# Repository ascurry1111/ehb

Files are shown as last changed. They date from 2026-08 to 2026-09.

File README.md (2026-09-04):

# EHB — Electric Handbells

Umbrella repo for a family of electric/electronic handbell products. Each
product's source is self-contained under `products/<name>/` — its own
README, 3D-print files, firmware, app code, and changelog live there and
don't mix with any other product's.

## Products

| Folder | Product | Status |
|---|---|---|
| [`products/electric-handbell`](products/electric-handbell/) | Solid-state electronic handbell: 3D-printed bell body with no moving parts, accelerometer-triggered wireless sound (BLE) | Active — v0.2 released |
| [`products/song-bell`](products/song-bell/) | Simpler 3D-printed bell that plays a song on its own | Planned |
| [`products/bell-pickup`](products/bell-pickup/) | Electronic adapter/pickup that retrofits onto a real (physical-clapper) handbell to trigger sound electronically | Planned |

See each product's own README for hardware, firmware, and build details.

## Repo conventions

- One folder per product under `products/`, each independently buildable —
  no product's firmware/app/model files reference another's.
- A shared root [`.gitignore`](.gitignore) covers common build/editor
  junk (Gradle, Arduino/PlatformIO, Python, OpenSCAD backups) across all
  products, since those patterns aren't product-specific.
- Per-product changelogs (e.g.
  [`products/electric-handbell/CHANGELOG.md`](products/electric-handbell/CHANGELOG.md))
  rather than one repo-wide log, since products version independently.

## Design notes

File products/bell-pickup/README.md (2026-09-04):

# Bell Pickup

An electronic adapter/pickup that retrofits onto a **real** handbell (one
with an actual clapper) to sense rings and trigger sound electronically —
unlike [`../electric-handbell`](../electric-handbell/), which is a
fully 3D-printed bell body with no moving parts, this attaches to an
existing physical bell.

**Status: planned.** Nothing has been designed yet; this folder is
scaffolding, kept separate from
[`../electric-handbell`](../electric-handbell/) so this product's files
never mix with that one's.

## Anticipated layout

```
3dprint/    Mounting/adapter hardware for attaching the pickup to a real bell
firmware/   Sensor + wireless firmware for the pickup
```

Likely shares a fair amount of firmware DNA with
[`../electric-handbell/firmware`](../electric-handbell/firmware/)
(accelerometer-based ring detection) — worth starting from a copy of that
rather than from scratch, though the mounting/sensing details will differ
since this senses a real clapper strike rather than being cast into a
purpose-built body.

Add a `CHANGELOG.md` here once there's a first release to log. Adjust the
layout above as the actual design takes shape — it's a starting point, not
a commitment.

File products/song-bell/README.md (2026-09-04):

# Song Bell

A simpler 3D-printed bell that plays a song on its own — no companion
receiver, no phone, no transmitter/receiver pair. Print the body, add the
electronics, and it plays a tune by itself.

**Status: planned.** Nothing has been designed yet; this folder is
scaffolding, kept separate from
[`../electric-handbell`](../electric-handbell/) so this product's files
never mix with that one's.

## Anticipated layout

Following the convention used by
[`../electric-handbell`](../electric-handbell/):

```
3dprint/    OpenSCAD model for the bell body
firmware/   Microcontroller firmware for on-board song playback
```

Add a `CHANGELOG.md` here once there's a first release to log. Adjust the
layout above as the actual design takes shape — it's a starting point, not
a commitment.

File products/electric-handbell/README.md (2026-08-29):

# Electric Handbell

A solid-state electronic handbell: a 3D-printed bell body with no moving
parts, instrumented with an accelerometer to detect ring gestures and
trigger sound electronically/wirelessly instead of with a physical clapper.

## Repo layout

```
3dprint/    OpenSCAD model for the bell body and printed test pieces
firmware/   ESP32 firmware (transmitter + receiver) and PC test tooling
android/    Android app for the v0.2 live-demo receiver (BLE-only)
```

## Hardware

- [Adafruit LIS3DH](https://www.adafruit.com/product/2809) accelerometer — senses the swing/ring motion
- [Adafruit ESP32 Feather V2](https://www.adafruit.com/product/5400) — reads the LIS3DH over I2C, transmits ring events wirelessly via ESP-NOW or BLE

See [firmware/README.md](firmware/README.md) for wiring, bring-up steps, and details on the wireless protocol.

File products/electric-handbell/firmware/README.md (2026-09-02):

# Wireless Handbell Prototype

## What's in here

```
feather_transmitter/feather_transmitter.ino   Feather ESP32 V2 — ring detection, BLE tx (v0.2: BLE-only)
devkit_receiver/devkit_receiver.ino           ESP32-DEVKITC-V4 — ESP-NOW rx, forwards to USB serial (v0.1 path)
receiver_tests/pc_serial_listener.py          PC — plays a tone from the ESP-NOW/serial path (v0.1 path)
receiver_tests/pc_ble_listener.py             PC — plays a tone from the BLE path directly
```

**v0.2 note:** `feather_transmitter.ino` was changed to BLE-only for the
Android demo (Android has no ESP-NOW support), which also removes the
WiFi/BLE radio-coexistence jitter noted below. The ESP-NOW + BLE dual-transport
version, and `devkit_receiver.ino`/`pc_serial_listener.py`'s upstream
counterpart, are preserved at the `v0.1` git tag if you need that path again.
For the live demo, see [`../android/HandbellReceiver`](../android/HandbellReceiver)
instead of the PC listeners.

## Wiring

LIS3DH → Feather ESP32 V2 (I2C):
- VIN → 3V
- GND → GND
- SDA → SDA
- SCL → SCL

If you have the STEMMA QT versions of both boards, just use the STEMMA QT cable and skip the wiring above entirely.

## Bring-up order (v0.2, BLE-only demo path)

0. **Set the mounting orientation first** — see [Ring detection](#ring-detection) below. Nothing will trigger correctly until `FORWARD_AXIS`/`FORWARD_SIGN` match your physical mounting.
1. **Flash `feather_transmitter.ino`** to the Feather. Open its Serial Monitor at 115200 baud — you should see its BLE address printed, then `RING #n peak=...g swing=...m/s` lines whenever you swing the bell forward and stop it.
2. **Test the BLE → PC path** (quick sanity check without the phone app): run `pc_ble_listener.py`. Swing the bell — you should hear a tone on the PC.
3. **Test the BLE → phone path**: build and run the Android app in
   [`../android/HandbellReceiver`](../android/HandbellReceiver) on the demo
   phone. Swing the bell — you should see the ring counter increment and hear
   a tone from the phone.

## Bring-up order (v0.1, ESP-NOW + BLE dual-transport — see the `v0.1` git tag)

1. **Flash `devkit_receiver.ino`** to the ESP32-DEVKITC-V4 first and open its Serial Monitor at 115200 baud. It prints its own MAC address on boot — copy it.
2. **Paste that MAC** into `RECEIVER_MAC` near the top of `feather_transmitter.ino`.
3. **Flash `feather_transmitter.ino`** to the Feather. Open its Serial Monitor too — you should see `My MAC: ...` and then `RING #n peak=...g` lines whenever you swing/tap the accelerometer.
4. Watch the DEVKITC-V4's Serial Monitor — you should see matching `RING,...` lines arrive there over ESP-NOW.
5. **Test the ESP-NOW → PC path**: run `pc_serial_listener.py --list` to find the DEVKITC-V4's port, then `pc_serial_listener.py --port <that port>`. Swing the bell — you should hear a tone.
6. **Test the BLE → PC path**: run `pc_ble_listener.py` (the DEVKITC-V4 isn't involved in this path at all — the Feather talks straight to the PC's Bluetooth radio). Swing the bell — you should hear a tone.

## Ring detection and damp

Detection models how a real handbell actually rings — a forward swing followed
by a **sudden stop** (which is when the clapper catches up and strikes) — rather
than "acceleration crossed a threshold," which is why earlier versions rang when
you merely picked the bell up or tapped the handle. See the `RING DETECTION`
comment at the top of `feather_transmitter.ino` for the full rationale.

A real handbell keeps ringing after the strike until it naturally damps out, or
until the ringer presses it to their body to stop it. The Android app plays a
multi-second decaying tone per ring rather than a short blip, and **damp** is
the gesture that cuts it short.

**Ring and damp are deliberately not symmetric.** A ring is directional — the
clapper only travels fore/aft and is sprung against striking backward. A damp
is *omnidirectional*: physically it's just "the casting contacted something,"
and in practice arm geometry means the bell usually comes back to the body
around 45° off the ring plane, laterally. So the stop is detected on the
**full 3D velocity vector**, as a deceleration measured *along the direction
of travel* rather than along any fixed axis.

**Both gestures share one armed state, and which one a motion was is decided
at the stop** — from the peak forward velocity accumulated over the whole
gesture — not when it arms. An earlier version armed each gesture separately
and that could not work: `speed >= |forwardVelocity|` by definition, so on a
forward swing the damp arm always tripped first and stole a large share of
rings, which then landed as silent damps. See `DECIDE AT THE STOP` in the
sketch's header comment for the full write-up; it's the kind of mistake worth
not repeating.

### Mounting orientation

`FORWARD_AXIS` / `FORWARD_SIGN` must match the physical mounting or nothing
works. They're preset to `AXIS_Z` / `-1.0` for the current build: the LIS3DH is
mounted flat on the rod's wide face with the component side outward, so the PCB
normal (Z) points at the ringer and forward — away from the ringer — is `-Z`.

**Verify the sign before tuning anything else.** The axis is confidently Z, but
the sign depends on which way the board faces and is easy to get backwards; a
flipped sign arms the detector on the backswing. Set `CALIBRATION_MODE 1`,
reflash, open Serial Monitor at 115200:

1. Hold the bell still in the ready position. The **dominant** `g=[]` value
   should be the in-plane axis running along the rod, with Z a minority
   component. If Z dominates, the board isn't mounted the way this config
   assumes and both settings need re-deriving.
2. Swing forward and confirm `vFwd` goes strongly **positive**. If it goes
   negative, flip `FORWARD_SIGN`.
3. Return `CALIBRATION_MODE` to `0`, reflash.

### Then: tune the thresholds

Every ring and damp prints `peakFwd=` and `peakSpd=`. Ring and damp several
times each and compare those numbers — that's the fastest way to see whether
the thresholds sit in the right place.

- **`RING_FORWARD_VELOCITY`** (m/s) — the ring/damp discriminator. At the
  stop, a gesture whose peak forward velocity reached this is a ring;
  anything less is a damp. **Lower it** if gestures you meant as rings are
  landing silently (check whether their `DAMP peakFwd=` sits just under this
  value — that's the tell). **Raise it** if damps are ringing the bell.
- **`RING_STOP_DECEL_THRESHOLD`** / **`DAMP_STOP_DECEL_THRESHOLD`** (m/s²) —
  how abruptly the bell must stop for each gesture to fire, measured along the
  direction of travel. Separate values because they're physically different
  events: arresting a committed swing versus resting the casting against your
  shoulder, so the damp threshold is set much lower. **Lower** whichever
  gesture is being missed entirely (nothing prints at all); **raise** it if
  incidental handling triggers that gesture.
- **`DAMP_CONTACT_JERK`** (m/s³) — how *suddenly* the deceleration must arrive
  for a damp to count as a contact. This exists because the damp threshold
  alone can't do the job: as you slow your arm approaching your shoulder, that
  voluntary slowdown produces a deceleration of similar *magnitude* to a gentle
  contact, so lowering the threshold enough to catch soft damps also makes it
  fire mid-approach, before the casting touches anything. Contact is
  distinguished by suddenness, not force — it changes acceleration within
  milliseconds where an arm slowdown ramps over 100ms+. **Lower it** if soft
  damps are missed (watch for `(damp: decel N ok, jerk N too soft)` in the
  serial log — that's this gate rejecting a gesture, and it names the number to
  beat); **raise it** if damps fire before the bell touches you.
- **`ARM_SPEED`** (m/s) — how fast the bell must move for the detector to
  start watching at all. Keep it comfortably below `RING_FORWARD_VELOCITY` so
  every real gesture gets watched early enough for its peaks to be captured,
  and low enough for a gentle damp — a gesture that never arms can't be
  detected no matter how low the stop thresholds go.
- **`POST_RING_DAMP_LOCKOUT_MS`** — suppresses a damp for this long after a
  ring, so the strike's own recoil can't kill the tone it just started. If
  rings sometimes cut themselves off, raise it; if quick ring-then-damp
  phrases feel unresponsive, lower it. Watch for `(recoil suppressed)` in the
  serial log — that's this guard firing.
- `RELEASE_VELOCITY` / `REFRACTORY_MS` — shared by both gestures; raise if one
  motion produces a burst of events.

Note that settling deliberately does **not** wait for the bell to come to
rest, only for the refractory window and the deceleration spike to pass —
ringing and then damping is one continuous motion, and requiring a full stop
in between made damps unreliable.

The defaults are reasoned starting points, not measured ones — expect to adjust
them against your actual bell.

**Set them from real data rather than guesswork:** `CALIBRATION_MODE 2` streams
`aFwd`, `vFwd`, `speed`, `cosFwd`, `decel` and `peakV` whenever the bell is
moving, with rings/damps still firing. Ring and damp normally a few times —
including damping from the awkward angles you'd actually use — then deliberately
do the things that *shouldn't* trigger either (pick the bell up, tap the handle,
tilt it slowly) and set each threshold in the gap between the groups.

**The failure mode to watch for** is a slow forward *tilt* arming the detector.
The sensor sits well above the wrist pivot and the bell rotates through a large
angle, so gravity rotates in the sensor's frame faster than the filter tracks
it, and the residue looks like forward acceleration. If tilting alone arms it,
lower `GRAVITY_LPF_ALPHA` so gravity is tracked faster — but not too far, since
it also starts absorbing genuine swing acceleration. With a single accelerometer
this can be traded off but not eliminated; a 6-DOF IMU with a gyro (LSM6DS3)
would remove the whole class of problem.

## Android

The full receiver app lives at [`../android/HandbellReceiver`](../android/HandbellReceiver),
not just a snippet — see its README for what it does and how to build it. The
GATT service exposes four characteristics, all under service UUID `6e400001-...`:

| Characteristic | UUID suffix | Purpose |
|---|---|---|
| Ring | `...0002` | Notify on every ring: `RingEvent` (uint32 ringId, uint16 peakMilliG, uint32 timestampMs) |
| Battery | `...0003` | Notify every 5s: `BatteryStatus` (uint8 percent, uint8 state, uint16 milliVolts, uint16 estimatedMinutesRemaining) |
| Time | `...0004` | Read-only, returns current `millis()` fresh each read — for clock-sync/latency measurement |
| Damp | `...0005` | Notify on the omnidirectional damp gesture: `DampEvent` (uint32 timestampMs) |

All multi-byte fields are little-endian.

## Known tuning issues (calibration TODO)

- **Dynamic level (peak-g) varies noticeably between rings that feel
  identical by hand.** Not yet root-caused — could be the accelerometer's ADC
  noise, the gravity-leakage effect described above, inconsistent physical
  technique, or some combination. Worth investigating with `CALIBRATION_MODE 2`
  traces of several "identical" rings side by side before retuning
  `DynamicLevel`'s g-value bands in the Android app.

## A note on BLE + ESP-NOW running together

Both use the ESP32's single 2.4GHz radio, just different protocol stacks (Bluetooth vs Wi-Fi-based ESP-NOW). Running both at once is supported and commonly done, but you may see occasional timing jitter or a dropped packet under heavy traffic since the radio is time-shared. For a bell that rings occasionally rather than continuously, this shouldn't be noticeable — but if you see issues, test each transport with the other's code commented out to isolate.

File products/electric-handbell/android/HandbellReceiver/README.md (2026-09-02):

# Handbell Receiver (Android)

A minimal Kotlin app for the v0.2 demo: connects to the Feather's
`WirelessHandbell` BLE peripheral and plays a tone on every ring. Built
specifically for a live demo on a OnePlus 15 Pro (Android 12+) — see
`minSdk = 31` in `app/build.gradle.kts`.

## What it does

1. On launch, requests `BLUETOOTH_SCAN`/`BLUETOOTH_CONNECT`, then scans for a
   device named `WirelessHandbell`.
2. Connects, requests `CONNECTION_PRIORITY_HIGH` (Android's fastest public
   connection-interval hint), and subscribes to ring notifications.
3. On each ring, plays a synthesized-ahead-of-time bell tone via `SoundPool`
   (the low-latency-appropriate Android API for short, frequently-retriggered
   sounds — no audio synthesis happens on the ring-event path itself, only
   `SoundPool.play()`), picking both tone and volume from the six musical
   dynamic levels (pp–ff) in [`DynamicLevel.kt`](app/src/main/java/com/ehb/handbell/DynamicLevel.kt).
   The tone is a several-second natural decay, not a short blip — see
   "Sustain and damp" below. Pitch is selectable — see "Pitch selection".
4. Auto-reconnects if the connection drops, so the demo can survive walking
   out of range briefly.
5. Separately (and at low priority — see the firmware header comment),
   displays battery percentage, an estimated time remaining, and whether
   the bell is charging / running on USB with no battery installed. This
   comes from a second, independent BLE characteristic the firmware updates
   every 5 seconds — it never competes with ring-event delivery.

See [`RingEvent.kt`](app/src/main/java/com/ehb/handbell/RingEvent.kt) for the
wire format (must match `RingEvent` in `feather_transmitter.ino`), and
[`BleRingClient.kt`](app/src/main/java/com/ehb/handbell/BleRingClient.kt) /
[`RingPlayer.kt`](app/src/main/java/com/ehb/handbell/RingPlayer.kt) for the
two halves of the pipeline.

## Building

This was authored file-by-file rather than generated by Android Studio, so
the Gradle wrapper jar isn't checked in (binary file, and there's no way to
verify one here without the Android tooling installed). To get it building:

1. Open this folder (`android/HandbellReceiver`) in Android Studio as a
   project.
2. Android Studio will notice the wrapper is incomplete and offer to fix it
   on sync ("Gradle wrapper is missing... " prompt) — accept it. If it
   doesn't prompt, run this from the project root once you have any Gradle
   installed:
   ```bash
   gradle wrapper --gradle-version 8.7
   ```
3. Let Gradle sync, then Run on the OnePlus 15 Pro over USB (with USB
   debugging enabled).

## Demo-day checklist

- **Disable battery optimization for this app** (Settings → Apps → Handbell
  Receiver → Battery → Unrestricted). Android will otherwise throttle BLE
  scanning/background radio activity to save power, which is exactly the
  wrong tradeoff mid-demo.
- **Keep the screen on** and the app in the foreground while demoing —
  BLE callbacks can be delayed once the app is backgrounded/doze-restricted.
- **Turn Bluetooth off and back on** beforehand if you've been testing other
  BLE peripherals, to clear any stale connection/bonding state.
- The on-screen ring counter and last-peak reading are there so you (and the
  audience) can see events land even before the tone finishes playing.

## UI notes

- **Battery** (top-left, small/dim) is deliberately out of the way — it's
  background info, not something to watch during a demo.
- **Latency** defaults to just the total. Tap the latency line to toggle the
  ring→phone / phone→sound breakdown on and off — there's no visible button
  for this by design; the ring log respects the same toggle.
- **Damp** button stops the currently sounding tone by hand. Deliberately
  obvious and easy to hit mid-demo, unlike the hidden latency toggle.
- **Ring log** lists every ring this session, newest first, in the same
  format as the "last ring" line. Tap **Clear** (top-right of the log
  section) to reset it — this only clears the on-screen log, it doesn't
  affect the running ring counter.

## About the latency reading

The Feather's clock (`millis()`) and the phone's clock are unrelated —
comparing `RingEvent.timestampMs` directly against a phone timestamp would be
meaningless. To bridge them, right after connecting the app reads a
clock-sync characteristic (`BLE_CHAR_TIME_UUID`) once, bracketing the round
trip with its own clock and taking the midpoint as the estimated offset
between the two clocks. This assumes the read is roughly symmetric (a fair
assumption given the ~7.5–15ms connection interval), and is accurate to
roughly half that round trip.

Given that offset, each ring reports:
- **Total latency** — from the Feather's detection instant to the app calling
  `SoundPool.play()`.
- **ring→phone** — detection instant to the BLE notification arriving.
- **phone→sound** — notification arriving to the `play()` call.

The one thing this *doesn't* capture: the actual acoustic output delay after
`play()` returns (audio HAL/mixer buffering) — there's no public Android API
that reports "audio is now audible," so `play()` returning is the best
available proxy. Expect the true perceived latency to run a little higher
than the number shown, by whatever that device's audio path adds.

Until the first sync completes (a few hundred ms after connecting), latency
reads "syncing clock…" rather than a wrong number.

### Where the remaining latency goes

Roughly, for a measured total in the low 20s of ms:

| Stage | Approx. | Controllable? |
|---|---|---|
| Sensor ODR + firmware polling (400Hz, both 2.5ms) | ~2–5ms | Only by raising ODR — see below |
| I2C read of the sample | ~0.15ms | Already at 400kHz fast mode |
| Detection + BLE notify queued | <0.5ms | Already minimal |
| **BLE connection interval wait** | **~5–11ms** | **No — this is the floor** |
| Android BLE stack → app callback | ~1–3ms | No |
| App callback → `SoundPool.play()` | <1ms | Already minimal |
| `play()` → actually audible | not measured | See the caveat above |

**The connection interval dominates and can't be pushed much further.** BLE's
spec minimum is 7.5ms, the firmware already requests it, and the app already
requests `CONNECTION_PRIORITY_HIGH` — but the *central* (the phone) decides,
and Android typically settles around 11.25ms regardless. A notification waits
on average half an interval, so ~5–6ms of the total is simply the radio, with
no public Android API to go lower.

**Raising the accelerometer ODR is the one remaining lever, and it is not
free.** The LIS3DH can run at 1.344kHz in high-resolution mode, which would
save a couple of ms. But three tuned constants are expressed in *samples*, not
time, and would all silently change meaning:
`REST_SAMPLES_REQUIRED` (40 = 100ms at 400Hz, would become 30ms),
`JERK_WINDOW_SAMPLES` (5 = 12.5ms, would become 3.7ms — directly changes the
damp contact test), and `GRAVITY_LPF_ALPHA` (0.997 ≈ a 1s time constant at
400Hz, would become ~0.3s). Changing ODR without re-deriving all three would
quietly break gesture detection. Worth doing deliberately, with the
`CALIBRATION_MODE 2` trace and time to retune — not as a latency tweak.

## About the battery reading

The Feather V2 has no fuel-gauge chip, so percentage/charging/no-battery are
all inferred from one noisy voltage reading on the firmware side — see the
`BATTERY TELEMETRY` comment at the top of `feather_transmitter.ino`. In
particular, "Charging" only appears once the firmware has seen voltage
*rising* over a ~60s window, so it lags a plug-in event by up to a minute;
a battery resting at or near full charge is reported as a plain percentage
rather than a guessed charge state.

## Sustain and damp

A real handbell keeps ringing after the strike until it naturally damps out,
or until the ringer presses it to their body to stop it. `RingPlayer` models
this: each tone is a multi-second decaying sustain (`DURATION_S`/
`BASE_DECAY_RATE`/`DECAY_RATE_SPREAD` in `RingPlayer.kt` — louder dynamics
ring out longer, same as a real bell has more energy to dissipate), and
`damp()` cuts it off early with a quick fade (~40ms — fast enough to feel
immediate, slow enough to avoid a click).

Two things trigger a damp:
- **The bell's damp gesture** — moving the bell in any direction outside the
  forward ring cone and stopping it (typically against the body). Detected on
  the firmware side; see `SUSTAIN AND DAMP` in `feather_transmitter.ino`.
- **The Damp button** in the app, for stopping a tone by hand. It acts on the
  local audio stream, so it works whether or not the bell is connected.

The bell is physically monophonic — one casting, one vibration state — so a
new ring always replaces whatever's currently sounding rather than layering a
second independent tone on top of it. Ring again mid-decay (without muting
first) and you'll hear the new strike cut the old one off, not overlap it —
which also matches normal handbell technique, where you don't have to damp
between every ring.

## Dynamics (volume) and tuning tone feel

Every ring is classified into one of six musical dynamic levels — pianissimo
through fortissimo — by [`DynamicLevel.kt`](app/src/main/java/com/ehb/handbell/DynamicLevel.kt),
which evenly divides the bell's observed realistic peak range (1.6g–5.0g,
from ring-log data) into six bands. The detected level (e.g. `mf`) is shown
next to the peak-g reading and in the ring log.

`DynamicLevel` is the single source of truth for both display and audio —
`RingPlayer` uses the same six levels for tone shape (brighter/longer at
higher levels) *and* playback volume, so they can't drift out of sync. Volume
is spread geometrically (equal ratio between consecutive levels) from 0.20 to
1.00, about 14dB pp-to-ff — geometric rather than linear because equal linear
steps sound bunched up at the loud end to the ear. (An earlier version had no
audible difference between levels at all: a per-buffer normalization step was
quietly canceling out the loudness scaling — see the comment atop
`RingPlayer.kt`. A later one ran 0.08–1.00, which made pp too quiet to hear
comfortably; a phone speaker's quiet end has to stay above the room, not just
above silence.)

To retune:
- **Dynamic boundaries** — adjust the g-value bands in `DynamicLevel.kt` if
  1.6g–5.0g stops matching what you observe in the ring log.
- **Volume spread** — adjust the six `volume` values on `DynamicLevel`'s
  entries directly (they're literals, not computed, so just edit them).
- **Tone shape** — `synthesizeBellTone()` in `RingPlayer.kt`, driven by
  `representativePeakG` per level.

## Pitch selection

Pitch controls sit near the top of the screen: a **Pitch** dropdown for
jumping straight to a specific note, and **-** / **+** buttons on either side
of it for nudging a half step at a time. Both cover the standard chromatic
range of a 5-octave handbell choir set — C3 to C8, 61 pitches, spelled with
flats (`Bb4`, not `A#4`) per handbell convention. See
[`HandbellPitch.kt`](app/src/main/java/com/ehb/handbell/HandbellPitch.kt) for
the full list and the equal-temperament frequency math (A4 = 440Hz). Defaults
to `A5` (880Hz) — what the tone was originally tuned to — and remembers your
last choice across restarts (`SharedPreferences`, not tied to any particular
bell).

**These two controls take different paths, and it matters for responsiveness:**

- The **dropdown** re-synthesizes all six dynamic-level tones at the new
  frequency on a background thread (~1s). The previous pitch's tones stay
  playable until the new ones are ready, so a ring mid-change never drops
  silently — worst case it plays once more at the old pitch. Rapid dropdown
  changes are also safe: `RingPlayer` tracks a generation counter and only
  the last selection's synthesis result gets applied.
- The **-/+ buttons** are instant. They don't re-synthesize at all — a
  semitone is a SoundPool playback-rate change of 2^(1/12), trivially inside
  its documented 0.5–2.0 range, so nudging just plays the already-loaded
  tones slightly faster or slower. `RingPlayer` lets this drift up to 9
  semitones before quietly re-synthesizing in the background to "rebase" and
  reset the rate to 1.0 (rate-shifting a fixed sample is only an
  approximation of a true pitch change; small shifts are convincing, but it
  gets audibly "sped up" well before a full octave). The dropdown's displayed
  selection stays in sync with nudges without re-triggering its own
  (slow) resynthesis path — see `nudgePitch()` in `MainActivity.kt` for how
  that's guarded.

One correctness note from extending the pitch range up to C8: the bell tone's
upper harmonics (`synthesizeBellRaw()`'s 2.4x/4.1x multipliers) would alias
above this app's 22050Hz sample rate at the top of that range — a harmonic
above Nyquist doesn't just disappear, it folds back down as audible noise.
Each harmonic is now faded out as it approaches Nyquist rather than left to
alias; inaudible at the original fixed A5 tuning, but real once pitch went
up to C8.

## Instruments

The **Sound** dropdown, just below Pitch, picks which of four procedural
synthesis voices plays your rings — see
[`Instrument.kt`](app/src/main/java/com/ehb/handbell/Instrument.kt) and the
generators in `RingPlayer.kt`:

- **Bell** (default) — the original tone: a decaying sine plus two
  *inharmonic* partials (2.4x/4.1x the fundamental). Inharmonicity is what
  makes a struck casting sound like a bell instead of a tuned string.
- **Piano** — a *true* harmonic series (1x, 2x, 3x, 4x) instead, with higher
  harmonics damping faster than the fundamental, the way a real struck
  string's higher modes actually behave.
- **Guitar** / **Electric Guitar** — Karplus-Strong: a noise-filled delay
  line, repeatedly read and fed back through a cheap lowpass + decay. This is
  a genuinely different algorithm from the two above, not just different
  parameters — no `sin()`/`exp()` in its per-sample loop at all, since a
  plucked string's "pluck then ring" character comes from resonating a noise
  burst rather than summing pure tones. It's also correspondingly cheaper to
  synthesize. Electric Guitar reuses the identical delay-line model with a
  brighter filter setting plus a mild soft-clip, for a grittier/more
  sustained character than the plain acoustic version.

**These are synthesizer approximations, not sampled recordings.** Organ,
trumpet, and clarinet were deliberately left out — they're sustained/blown
voices that don't fit the strike-and-decay physical model the rest of this
app (and a real handbell) is built around, and procedural synthesis of them
specifically would land pretty far from convincing. A soundfont + real synth
engine (e.g. FluidSynth) would give authentic sampled timbres for a much
wider instrument set, but means replacing this whole `SoundPool`-based
playback pipeline with a persistent MIDI-style synth, plus bundling a
soundfont asset (tens to 100+MB) and a native/JNI dependency — a much larger,
riskier undertaking, set aside for now in favor of what could actually be
built and reasoned about correctly without a real device to test against
throughout.

Switching instruments takes the same background re-synthesis path as the
pitch dropdown (~1s) — there's no fast nudge equivalent for this one, since
instrument choice is an occasional per-demo setting rather than something
changed rapidly mid-performance.

**Unlike a pitch change, an instrument change blocks rather than falls back.**
Hearing the old *pitch* for one more ring during a pitch-dropdown transition
is a harmless, barely-noticeable approximation. Hearing the *wrong instrument
entirely* is not — it reads as a bug, not a brief delay. So while
`RingPlayer.setPitch()` keeps the previous tones playable until the new ones
land, `setInstrument()` suppresses playback outright for that window (a ring
that lands mid-change is still counted/logged normally — only its *sound* is
dropped) and drives a full-screen overlay (`busyOverlay` in
`activity_main.xml`, wired via `RingPlayer.setOnBusyChangedListener`) that
also blocks touches to the rest of the UI, so the pitch/instrument controls
can't be poked again mid-change to start a second overlapping request.

**Known limitation:** Karplus-Strong's delay line length must be a whole
number of samples, so tuning accuracy degrades at high pitches where
`sampleRate / frequency` is small — at C8 (~5.3 samples) the nearest
achievable length is audibly sharp or flat by close to a semitone. Fixable
with fractional-delay interpolation; not implemented, since the guitar
voices are unlikely to be played at the very top of a handbell set's range
in practice.

## App icon

The launcher icon is a stylised version of the physical bell: the gold
casting tipped 45° with the mouth up-left and handle down-right (matching
the build photo), over a radial gradient from soft champagne at the centre
to neutral slate grey at the rim, with a small Bluetooth badge upper right.

It's **pure vector** — two `VectorDrawable`s
([`ic_launcher_background.xml`](app/src/main/res/drawable/ic_launcher_background.xml),
[`ic_launcher_foreground.xml`](app/src/main/res/drawable/ic_launcher_foreground.xml))
composed as an adaptive icon. No raster assets, so it stays sharp at every
density and there are no PNGs to regenerate when the design changes.

Two things worth knowing before editing it:

- **The bell is authored upright and tipped by one group rotation.** Every
  coordinate in the foreground is in vertical space, with a single
  `android:rotation="-45"` on the enclosing group doing the tilt. Editing
  the shape means editing sensible vertical coordinates; hand-computing
  rotated ones would be miserable and pointless.
- **Everything sits inside a radius-36 circle around (54,54).** Adaptive
  icons are 108×108 but only the central 72×72 is guaranteed unmasked, and
  launchers mask to different shapes. Rotation preserves distance from the
  pivot, so the safe-zone check is just "is every authored point within 36
  of centre" — the values are listed in the file's header comment. The
  Bluetooth badge is the tightest at 35.4, so give it room if you move it.

There's no legacy PNG fallback and none is needed: `minSdk` is 31, so every
device that can install this supports `mipmap-anydpi-v26`.

Not implemented: a `<monochrome>` layer for Android 13+ themed icons. That
only appears if the user has themed icons switched on (off by default), so
it's polish rather than a gap — but it's the obvious next addition if the
icon ever looks out of place on a themed home screen.

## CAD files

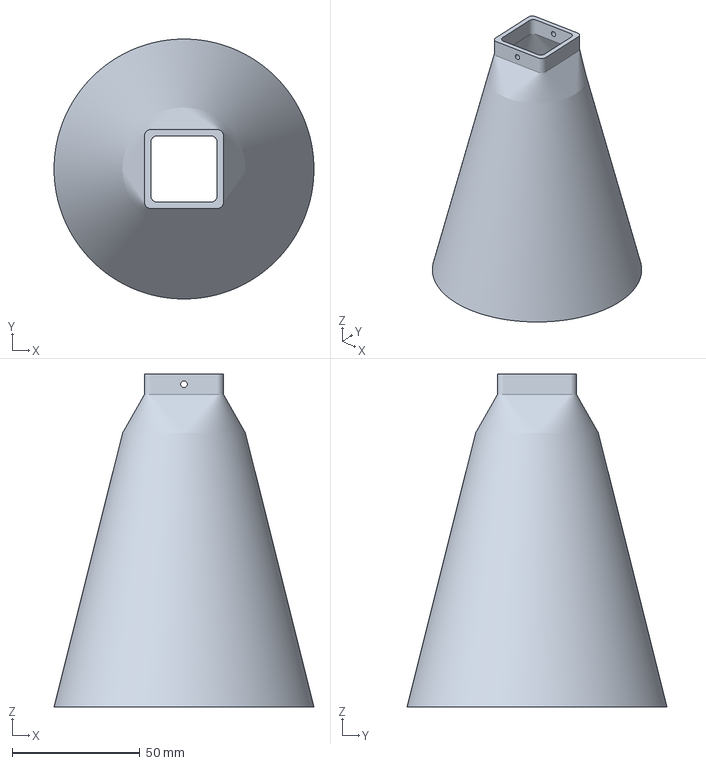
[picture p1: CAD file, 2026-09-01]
products/electric-handbell/3dprint/cone.3mf
101.6 x 101.6 x 130.2 mm

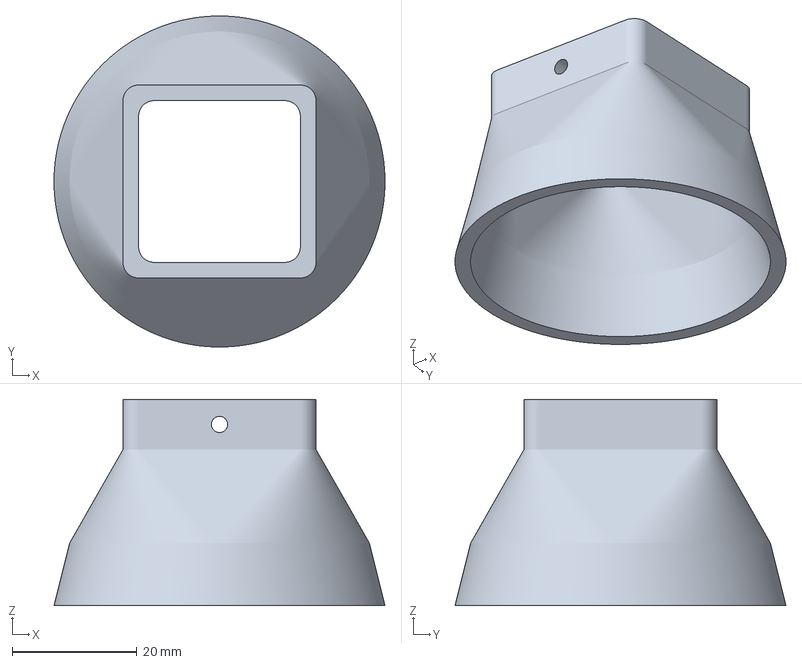
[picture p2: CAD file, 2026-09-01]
products/electric-handbell/3dprint/TestPrints/test_cone_collar.3mf
53.0 x 53.0 x 33.0 mm

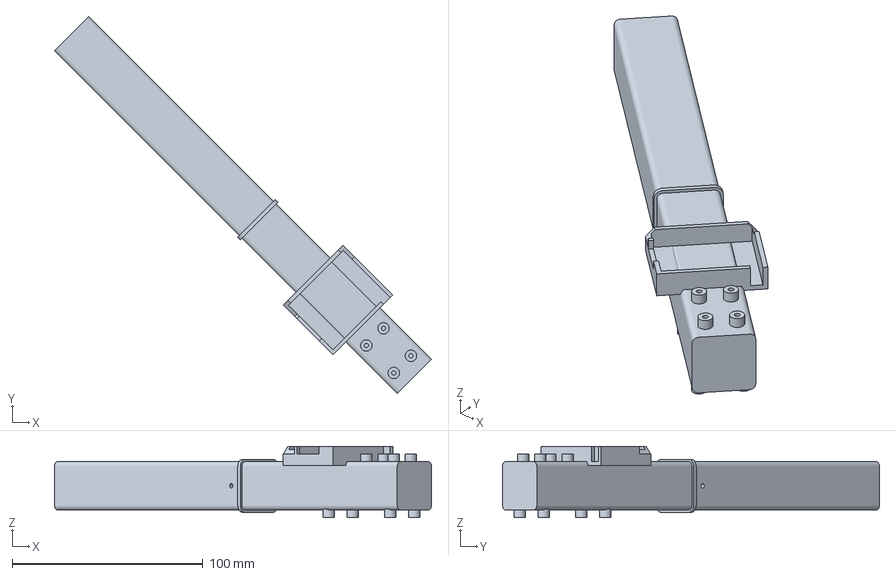
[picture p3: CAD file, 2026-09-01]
products/electric-handbell/3dprint/rod.3mf
197.6 x 197.6 x 37.4 mm

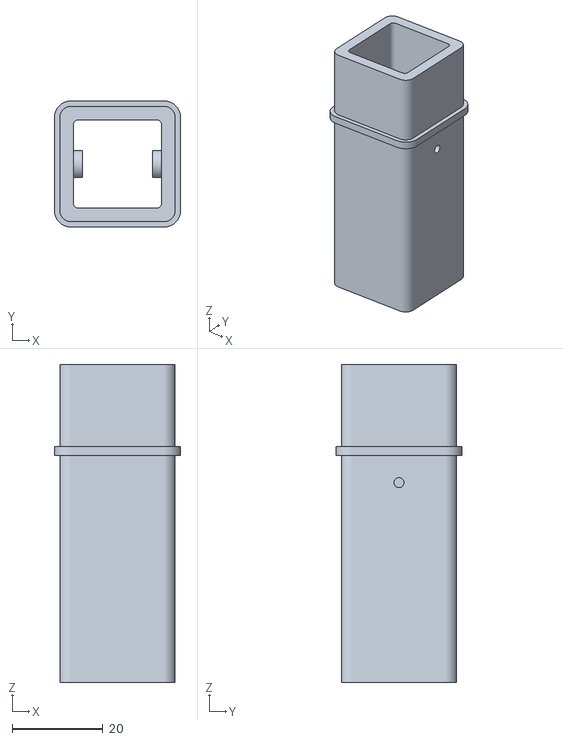
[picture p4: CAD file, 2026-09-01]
products/electric-handbell/3dprint/out/test_rod_collar.stl
27.8 x 27.8 x 70.0

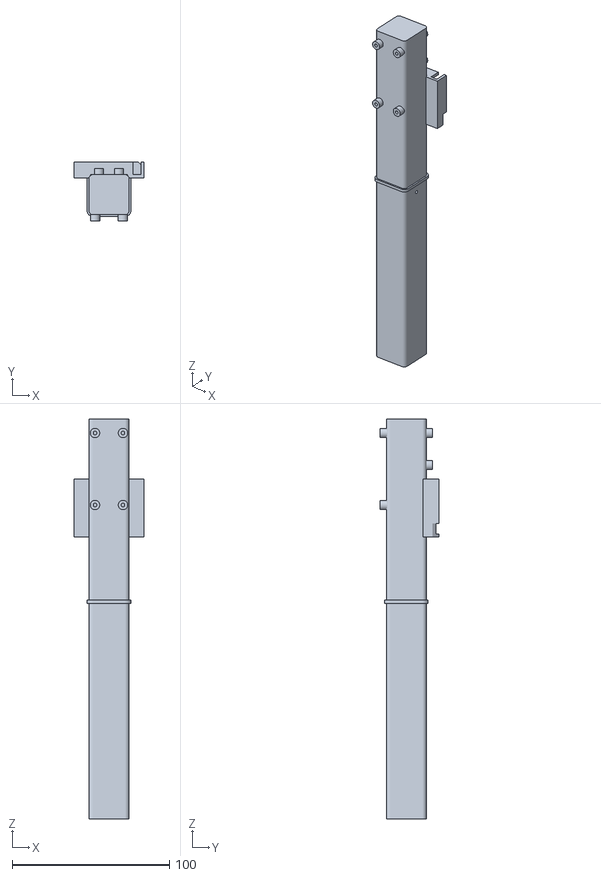
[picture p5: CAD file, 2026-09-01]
products/electric-handbell/3dprint/out/rod.stl
44.4 x 37.4 x 254.0

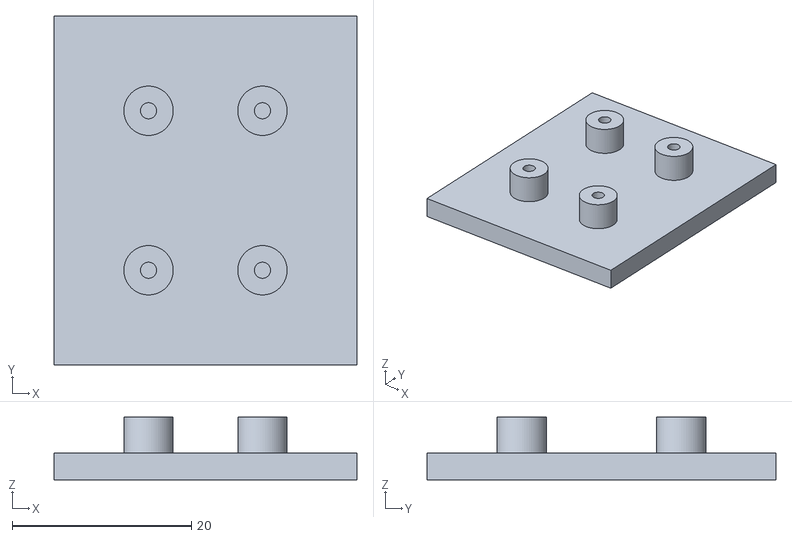
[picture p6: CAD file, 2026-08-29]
products/electric-handbell/3dprint/TestPrints/test_lis3dh_plate.stl
33.8 x 38.9 x 7.00

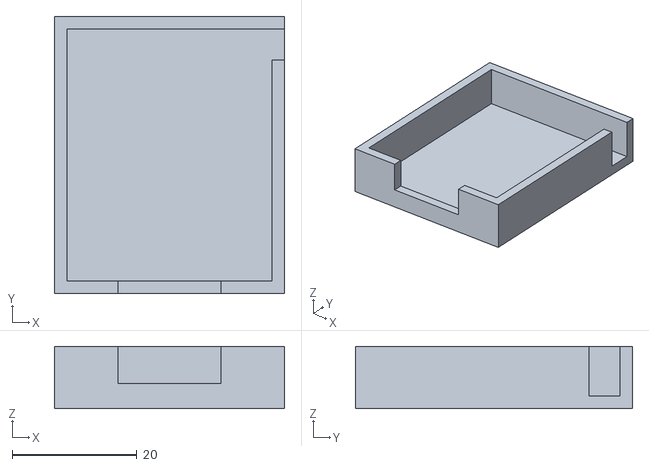
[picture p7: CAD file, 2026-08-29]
products/electric-handbell/3dprint/TestPrints/test_battery_cradle.stl
36.9 x 44.4 x 10.0

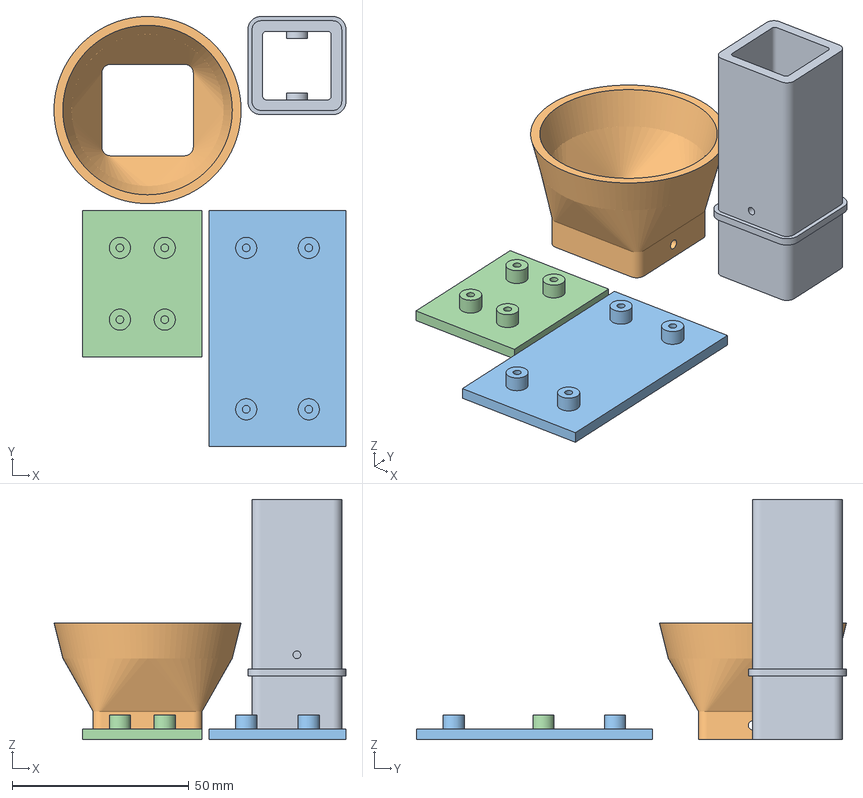
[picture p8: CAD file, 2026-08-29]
products/electric-handbell/3dprint/TestPrints/TestPieces.3mf
82.7 x 121.8 x 68.0 mm
test_rod_collar_v2.stl
test_cone_collar_v2.stl
test_feather_plate_v3.stl
test_lis3dh_plate_v3.stl

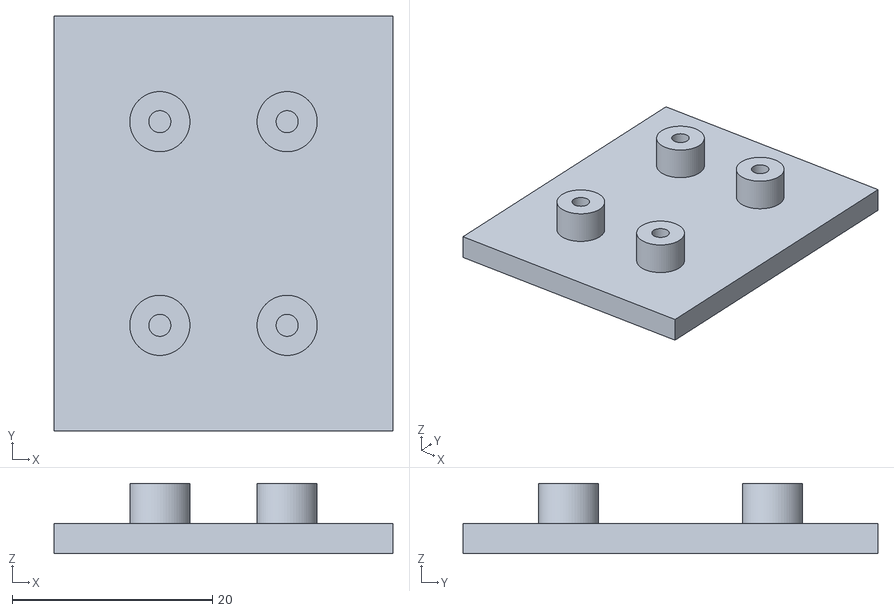
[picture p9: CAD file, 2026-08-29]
products/electric-handbell/3dprint/TestPrints/test_lis3dh_plate_v3.stl
33.8 x 41.4 x 7.00

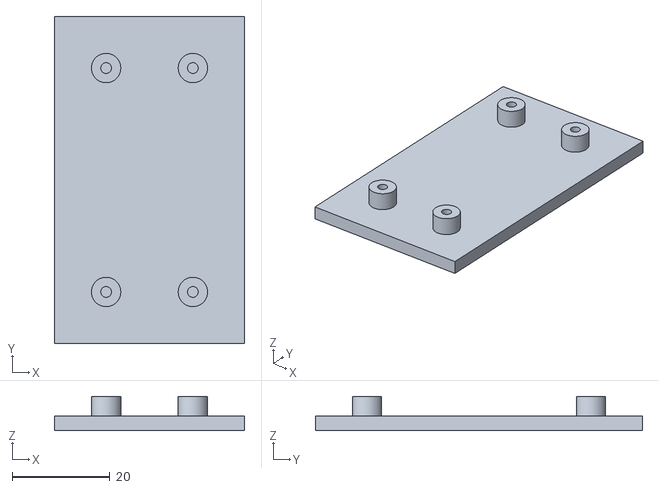
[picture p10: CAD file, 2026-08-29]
products/electric-handbell/3dprint/TestPrints/test_feather_plate_v3.stl
38.8 x 66.8 x 7.00

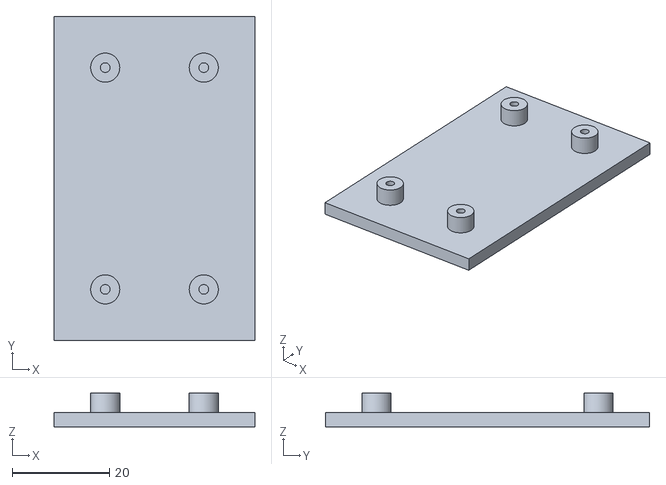
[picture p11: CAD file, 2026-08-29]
products/electric-handbell/3dprint/TestPrints/test_feather_plate.stl
41.4 x 66.8 x 7.00

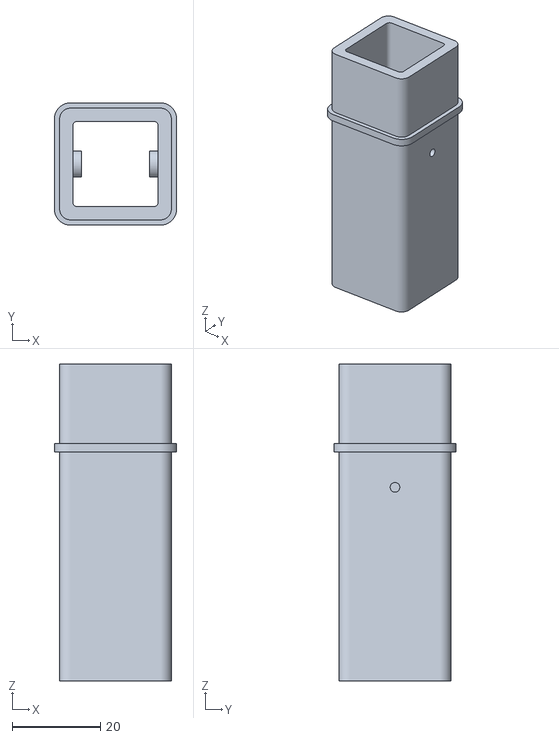
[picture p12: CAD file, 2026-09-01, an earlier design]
products/electric-handbell/3dprint/TestPrints/test_rod_collar_v3.stl
27.8 x 27.8 x 72.0

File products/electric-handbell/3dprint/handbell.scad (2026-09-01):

/* ============================================================================
   Wireless Handbell — Prototype Enclosure (Rod/Handle + Detachable Cone Bell)
   v4 — corrected orientation, enclosed battery pocket, positive-lock cone
   ============================================================================
   Two parts, meant to be rendered and exported to STL separately:
     - "rod"  : the 9.5" handle. z=0 is the BARE BOTTOM END you hold. z
                increases going UP toward the cone — the electronics live up
                near the top, inside the cone, as far from your hand as the
                design allows (for better swing-motion sensing). LIS3DH and
                Feather mount externally on opposite faces via standoff
                bosses; a silicone-lined battery cradle (design from your
                collaborator's Battery_Slot.scad, integrated as a
                floor-less sleeve — the rod's own surface is the pocket
                floor) sits below the LIS3DH.
     - "cone" : the detachable conical bell shell. Its narrow end has a
                square socket that slides over the top of the rod and locks
                in place with two retention screws against a stop ridge
                (see "CONE ATTACHMENT" below) — no more friction-fit alone.

   ORIENTATION FIX (this was wrong in earlier versions)
   Your original spec measures "5 inch handle" from the BOTTOM of the rod,
   with the cone starting at the 5" mark and continuing UP and OUT past the
   rod's far end. Electronics are "0.5in down from the TOP" — the top being
   that same far end, which sits INSIDE the cone once assembled. Earlier
   versions of this file had the coordinate system backwards, which put the
   electronics near the free grip end (close to your hand) instead of
   inside the cone (far from it). This version fixes that: z=0 is the plain
   grip end, z=rod_length is the end inside the cone.

   BATTERY CRADLE (from your collaborator's Battery_Slot.scad)
   Integrated as a floor-less sleeve unioned onto the rod, oriented so its
   length axis (the "long sides," 44.4mm outer — the battery-length
   direction where the wire notch sits) runs vertically, notch at the top,
   wire pointing up toward the Feather/LIS3DH. Its depth axis (originally
   the pocket's open/up direction) now points radially outward from the
   rod's surface, so the pocket opens away from the rod like a normal
   external mount, and the rod's own surface serves as the pocket's floor
   — no separate printed floor. See "BATTERY CRADLE" section below for the
   exact axis mapping and the gap adjustment this required.

   CONE ATTACHMENT — stop ridge + retention screws (replaces plain friction)
   A friction-only fit is genuinely hard to get right (too tight risks
   cracking the rod on removal; too loose and it rattles or slides), and
   gives no clear "correct position." This version adds:
     - A raised STOP RIDGE on the rod, right where the collar should end —
       the cone physically can't slide past it, so there's exactly one
       insertion depth, no guesswork.
     - Two small SELF-TAPPING SCREWS, driven through small clearance holes
       in the cone's collar into blind pilot holes in the rod. The rod's
       OUTER surface stays perfectly flat at these holes — the extra
       material needed for good thread depth is added on the INSIDE
       instead (into the hollow interior, invisible from outside), so the
       cone never has to know it's there and only needs a small clearance
       hole for the screw shank. An external boss was tried first, but it
       needed a big clearance slot in the collar to let it slide past
       during insertion, which cut into the collar's structural
       integrity — the inward version gives the same thread depth with
       none of that cost. A snap-detent click was also considered, but a
       rigid bump would have to squeeze past the entire solid collar wall
       on the way in (not just click at the end), which risks the same
       "too tight" problem this is meant to solve — screws avoid that
       entirely.
     - The collar's own clearance is loosened, since it no longer has to
       do the retention work by itself — it just has to guide the cone
       into alignment as you slide it up to the stop.
   Removal: back out two screws, then pull straight down. No force-fit,
   no risk of gouging the rod.

   HOW TO USE
     1. Open this file in OpenSCAD (openscad.org, free).
     2. Set the `part` variable below to one of: "rod", "cone", or one of
        the five test prints (see "TEST PRINTS — how to use" near the
        bottom of this file for the full list).
     3. F6 to render, then File > Export > Export as STL.
     4. Repeat with other part values for the other STLs.
     Leave `part` as "both" for a combined preview of the rod+cone only —
     don't export STL in that mode.

   ASSUMPTIONS TO VERIFY BEFORE PRINTING
     - LIS3DH mounting hole spacing is an estimate (Adafruit doesn't
       publish it) — measure your actual board and adjust lis3dh_* below.
     - Lock screw fit (clearance hole / pilot hole sizing) and the stop
       ridge's clearance are FDM-printer-dependent — see the
       "test_rod_collar" / "test_cone_collar" test prints near the bottom
       of this file for a small, focused way to check that fit.
     - The battery pocket / collar-clearance spacing has a WARNING echo
       that fires if a future change to board offsets, the battery gap, or
       collar length pushes them too close together again — currently
       there's a comfortable margin, but this has been tight before after
       parameter changes, so it's worth a glance if you adjust any of
       those.
   ============================================================================ */

part = "rod";  // "rod", "cone", "both" (preview only), or one of the five test
                 // prints: "test_feather_plate", "test_lis3dh_plate",
                 // "test_battery_cradle", "test_rod_collar", "test_cone_collar"
                 // — see "TEST PRINTS — how to use" near the bottom of this file.

$fn = 64;

// ---------------------------------------------------------------------------
// UNITS
// ---------------------------------------------------------------------------
IN = 25.4;

// ---------------------------------------------------------------------------
// ROD / HANDLE
// z=0 is the bare bottom end (your hand grips here). z increases going up
// toward the cone.
// ---------------------------------------------------------------------------
rod_length    = 10.0 * IN;   // 254.0 mm, total rod length
rod_side      = 1.0 * IN;    // 25.4 mm, square cross-section — exact 1"
rod_corner_r  = 2.5;         // mm, rounded corner radius — kept modest so there's
                              // enough flat area near the edges for standoffs, since
                              // both boards' mounting holes sit close to their own
                              // edges (Feather is 22.8mm wide, LIS3DH narrower still,
                              // both comfortably inside the rod's 25.4mm width now —
                              // this value has margin to spare, not a tight fit)
rod_wall      = 3;           // mm, wall thickness of the hollow rod (weight/filament savings)
handle_length = 5.0 * IN;    // 127 mm, bare grip length from the bottom
bottom_cap_thick = rod_wall;  // mm — solid cap at the BOTTOM (the free grip end).
                                // (Was called top_cap_thick — legacy name from before
                                // the ORIENTATION FIX above; renamed now that there's
                                // a real top_cap_thick too, see below.)
top_cap_thick = rod_wall;    // mm — solid cap at the TOP (the end that sits inside
                              // the cone). Originally left open there on purpose, but
                              // an open top means the slicer sees the internal
                              // lock-screw bosses (rod_lock_pilot_bosses(), floating
                              // cylinders inside the hollow interior) as overhangs into
                              // open air and wants to support into the cavity from
                              // above — capping both ends encloses the interior fully,
                              // so it's just a normal internal void the slicer fills
                              // per its own infill settings instead.

cone_attach_z = handle_length;  // 127 mm — the cone's collar starts here and covers the rest of the rod
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

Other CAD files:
products/electric-handbell/3dprint/out/cone.stl
products/electric-handbell/3dprint/out/test_cone_collar.stl
products/electric-handbell/3dprint/TestPrints/test_cone_collar_v3.stl
products/electric-handbell/3dprint/TestPrints/test_rod_collar.3mf
products/electric-handbell/3dprint/TestPrints/test_rod_collar_v4.stl
products/electric-handbell/3dprint/TestPrints/test_feather_plate_v2.stl
products/electric-handbell/3dprint/TestPrints/test_cone_collar.stl
products/electric-handbell/3dprint/TestPrints/test_cone_collar_v2.stl
products/electric-handbell/3dprint/TestPrints/test_lis3dh_plate_v2.stl
products/electric-handbell/3dprint/TestPrints/test_rod_collar.stl
products/electric-handbell/3dprint/TestPrints/test_rod_collar_v2.stl
products/electric-handbell/3dprint/cone.stl
products/electric-handbell/3dprint/rod.stl

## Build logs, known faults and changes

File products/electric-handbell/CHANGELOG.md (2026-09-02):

# Changelog

## v0.2 — 2026-09-01

Live-demo path: Android phone as receiver, BLE-only, tuned for low latency.
Confirmed working on hardware end to end, at ~22ms average ring-to-sound.

Known items deliberately left for v0.3, all documented in the relevant
README rather than only here:
- Dynamic level varies noticeably between rings that feel identical by hand
  (root cause not yet identified — see the tuning-TODO list in
  `firmware/README.md`).
- Ring/damp thresholds are reasoned starting points refined by feel, not
  measured against trace data across a range of ringers.
- Karplus-Strong tuning drifts at the very top of the pitch range
  (integer-sample delay length; fixable with fractional-delay interpolation).
- Raising the accelerometer ODR would cut a few ms of latency but requires
  re-deriving three sample-count-based tuning constants first.

- `feather_transmitter.ino`: dropped ESP-NOW/WiFi entirely (Android has no
  ESP-NOW support; also removes WiFi/BLE coexistence jitter). Raised LIS3DH
  output data rate to 1.6kHz and removed the polling throttle. Firmware now
  requests a 7.5–15ms BLE connection interval with zero slave latency as
  soon as a phone connects, and raises BLE TX power to +9dBm. The old
  dual-transport version is preserved at the `v0.1` git tag.
- New [`android/HandbellReceiver`](android/HandbellReceiver) app: scans for
  `WirelessHandbell`, subscribes to ring notifications, requests
  `CONNECTION_PRIORITY_HIGH`, and plays a pre-synthesized bell tone via
  `SoundPool` (velocity-sensitive across three peak-g buckets) with no
  synthesis work on the ring-event hot path. Auto-reconnects on drop.
- Battery telemetry, sampled at low priority (every 5s, never gating the
  ring path): percentage, estimated time remaining, and whether the bell is
  charging / running on USB with no battery — all inferred from a single
  voltage reading over time, since the Feather V2 has no fuel-gauge chip.
  Sent over a second BLE characteristic and shown in the Android app.
- End-to-end ring-to-tone latency, shown in the app on every ring. A new
  clock-sync characteristic lets the phone estimate the offset between its
  own clock and the Feather's `millis()`, so `RingEvent.timestampMs` can be
  compared against the phone's clock. Breaks the total down into
  ring→phone (BLE) and phone→sound (app) legs.
- Ring detection rewritten to model real handbell physics: a forward swing
  followed by a sudden stop, rather than a bare acceleration threshold.
  Gravity is now filtered out, forward acceleration is integrated into a
  velocity, and a ring fires only when the bell was genuinely travelling
  forward and then decelerated sharply. This rejects the old false triggers
  (picking the bell up, tapping the handle, backswing, and bursts of
  multiple rings per motion). LIS3DH moved to 400Hz/12-bit high-resolution,
  since the velocity integration needs resolution more than raw sample rate.
  Requires setting `FORWARD_AXIS`/`FORWARD_SIGN` for your mounting — there's
  a `CALIBRATION_MODE` to determine them.
- UI pass: battery moved to a small, dim top-left corner (out of the way);
  latency defaults to just the total, tap it to toggle the breakdown; added
  a scrolling ring log (newest first, same info as "last ring") with a
  Clear control.
- Expanded from three ad-hoc tone "buckets" to the six standard musical
  dynamic levels (pp–ff), evenly spread across the bell's observed realistic
  peak range (1.6g–5.0g). New `DynamicLevel.kt` is the single source of
  truth for both tone/volume (`RingPlayer`) and the detected-dynamic display
  (shown next to peak-g and in the ring log). Also fixed a real bug where
  playback volume never actually varied between levels — a per-buffer
  normalization step was canceling out the loudness scaling, leaving only a
  timbre difference — and widened the volume spread to ~22dB pp-to-ff.
  (Known open issue: dynamic level still varies noticeably between rings
  that feel identical by hand — see `firmware/README.md`'s tuning-TODO list.)
- Sustain and damp: tones now ring out for several seconds with a natural
  decay (longer for louder dynamics) instead of a ~1s fixed blip, and a
  **damp** gesture cuts the tone short, modeling how a real handbell is
  stopped by pressing it to the chest/shoulder. New `BLE_CHAR_DAMP_UUID`
  characteristic; ring and damp share one state machine (`RING_IDLE`/
  `RING_ARMED_FORWARD`/`RING_ARMED_DAMP`/`RING_SETTLING`). The bell is
  treated as physically monophonic on the Android side — a new ring replaces
  whatever's currently sounding rather than layering. Also fixed a latent
  bug found while extending this: the old peak-velocity tracker only ever
  recorded positive (forward) values, so it read ~0 during a backward swing.
- Damp detection made omnidirectional. It was first implemented as the
  mirror image of ring detection (backward motion along the forward axis),
  which forced the ringer to rotate the bell in-hand to damp it — arm
  geometry means the bell actually comes back to the body around 45° off the
  ring plane. Damp now integrates the **full 3D velocity vector**, arms on
  speed in any direction outside a forward exclusion cone
  (`DAMP_EXCLUSION_COS`, default 45°), and fires on deceleration measured
  along the direction of travel rather than any fixed axis. Ring detection
  stays single-axis and directional, as the clapper physics require — the
  exclusion cone is what keeps a forward swing from damping its own tone.
- Fixed ring/damp detection dropping ~60% of gestures (regression from the
  omnidirectional damp change above). Two structural bugs:
  1. **Arming race.** Ring and damp each had their own armed state, entered
     on their own threshold. But `speed >= |forwardVelocity|` by definition,
     so on a forward swing the damp threshold was always crossed first, and
     a real swing's arc wanders in and out of any forward cone — so the damp
     state routinely stole ring gestures, which then landed as silent damps.
     Tuning the cone only traded ring misses for damp misses. Now there is
     ONE armed state and the gesture is classified **at the stop**, from the
     peak forward velocity over the whole motion, which separates the two
     cleanly.
  2. **Settle deadlock.** Settling waited for the bell to come to rest, but
     ringing and then damping is one continuous motion — the bell never
     stops in between — so the detector sat in settling right through the
     damp. It now waits only for the refractory window and the deceleration
     spike to pass.
  Also added `POST_RING_DAMP_LOCKOUT_MS`, needed by the new design: the
  strike's recoil is real motion ending in a real deceleration, and would
  otherwise read as a damp and kill the tone it just started.
- Damps now fire on *contact* rather than on deceleration magnitude alone.
  Lowering `DAMP_STOP_DECEL_THRESHOLD` far enough to catch gentle damps also
  caught the arm's own slowdown while approaching the shoulder — the two are
  similar in magnitude, so no threshold separates them. What does separate
  them is suddenness: contact changes acceleration within milliseconds, an
  arm slowdown ramps over 100ms+. A damp now additionally requires a jerk
  spike (`DAMP_CONTACT_JERK`), which lets the deceleration threshold stay low
  enough for soft damps without firing mid-approach. Ring keeps a
  magnitude-only test — its threshold is already well above any voluntary arm
  motion.
- Soft damps now register. A damp can be a far gentler motion than a ring —
  resting the casting against a shoulder rather than arresting a committed
  swing — so it gets its own, much lower stop threshold
  (`DAMP_STOP_DECEL_THRESHOLD`, half the ring's), and `ARM_SPEED` was lowered
  so gentle gestures arm at all. The fix above had merged the two thresholds
  on the reasoning that the stop must be detected before the gesture can be
  classified; that was wrong — the classification input is a running peak
  available at every sample, so the applicable threshold is known
  continuously.
- Manual **Damp** button in the app, for stopping a tone by hand. Acts on
  the local audio stream, so it works with or without the bell connected.
- Raised the dynamic volume floor from 0.08 to 0.20 (now ~14dB pp-to-ff
  instead of ~22dB) — pp was too quiet to hear comfortably. A phone
  speaker's quiet end has to stay above the room, not just above silence.
- Pitch selection. New `HandbellPitch.kt` covers the standard chromatic range
  of a 5-octave handbell set (C3–C8, 61 pitches, flat spellings per handbell
  convention). A dropdown near the top of the app picks the pitch, defaulting
  to `A5` (880Hz, what the tone was already tuned to) and persisting the
  choice across restarts. `RingPlayer` re-synthesizes all six dynamic levels
  at the new frequency on a background thread; the previous pitch's tones
  stay playable until the new ones are ready (generation-counter guarded
  against rapid changes racing each other), so a ring mid-change never drops.
- Instant +/- half-step nudge buttons flanking the pitch dropdown. These
  don't re-synthesize (the dropdown's ~1s re-synthesis was too slow for a
  one-button nudge) — a semitone is a SoundPool playback-rate change of
  2^(1/12), so a nudge just replays the already-loaded tones at a shifted
  rate. `RingPlayer` lets that drift up to 9 semitones (safely inside
  SoundPool's 0.5–2.0 rate range) before quietly re-synthesizing in the
  background to rebase, invisibly to the caller.
- Fixed harmonic aliasing at high pitches. `synthesizeBellTone()`'s upper
  harmonics (2.4x/4.1x the fundamental) were inaudibly above Nyquist at the
  original fixed A5 tuning, but pitch selection's range now reaches C8
  (4186Hz), where the same harmonics land at ~10–17kHz — above this app's
  22050Hz sample rate's Nyquist, where they'd fold back down as audible
  noise rather than simply disappear. Each harmonic now fades out as it
  approaches Nyquist instead.
- Instrument selection: a **Sound** dropdown picks between four procedural
  synthesis voices (Bell, Piano, Guitar, Electric Guitar) — new
  `Instrument.kt`, and per-instrument raw-waveform generators in
  `RingPlayer.kt` (`synthesizeBellRaw()` is the renamed original tone).
  Guitar/Electric Guitar use Karplus-Strong (a noise-filled delay line fed
  back through a lowpass + decay) rather than summed sine waves — a
  genuinely different, and cheaper, algorithm, chosen because a plucked
  string's character comes from resonating noise rather than summing pure
  tones. Piano uses a true harmonic series (unlike the bell's deliberately
  inharmonic partials) with higher harmonics damping faster than the
  fundamental. Switching instruments re-synthesizes on a background thread,
  same safety properties as the pitch dropdown. Organ/trumpet/clarinet were
  considered and dropped — sustained/blown voices don't fit the
  strike-and-decay model everything else here is built around. A soundfont +
  native synth engine (e.g. FluidSynth) would give authentic sampled
  instrument timbres across a much wider set, but was set aside as a
  separate, much larger undertaking requiring a native/JNI dependency and a
  large bundled asset that couldn't be built and verified without a real
  device to test against throughout — see the "Instruments" section of the
  Android README for the full reasoning.
- Instrument changes now block rather than fall back. Hearing the old pitch
  for one more ring mid-transition is harmless; hearing the wrong instrument
  entirely reads as a bug, not a brief delay. `RingPlayer.setInstrument()`
  now suppresses playback for the ~1s re-synthesis window (a ring landing
  mid-change is still counted/logged, just silently — only its sound is
  dropped) and a new `setOnBusyChangedListener` drives a full-screen
  overlay with a status message that also blocks touches to the rest of
  the UI, so the controls can't be poked again mid-change to start a
  second overlapping request. Pitch changes are unaffected and keep their
  existing fall-back-to-old-tone behavior. Synthesis failures (e.g. an
  unexpected exception mid-render) now always clear the busy state rather
  than risking a permanently grey-locked UI, given the new stakes of
  leaving it stuck.

- Latency reduction pass, targeting the measured ~30ms ring-to-sound time.
  Three fixes, all on the path itself:
  - **App: play the tone on the BLE callback thread**, before hopping to the
    main thread. `onRing` previously went through `runOnUiThread` and then did
    a `String.format` and three view updates *before* calling `play()` — despite
    a comment claiming it played first with "no extra work before it." The
    sound was waiting on the main looper (behind any in-progress frame) and
    then on the app's own UI work. Split into `onRingUi` for everything
    non-urgent; likely the largest single win.
  - **Firmware: notify before logging.** `emitRing()` ran a `Serial.printf`
    with three `%f` conversions *before* `notify()`, putting float formatting
    and a 115200-baud write directly in the latency path. Pure reordering.
  - **Firmware: I2C at 400kHz** (`Wire.setClock`) instead of Arduino's 100kHz
    default. Cuts ~0.6ms of blocking bus time per sample read down to ~0.15ms,
    and that time is on the path since detection can't run until the read
    finishes.
  Also added `audioLock` in `RingPlayer` to serialize `play()`/`damp()` and the
  damp fade steps — they used to get that for free by both running on the main
  thread, so it's required now that `play()` comes in off-thread.
  Documented the full remaining latency budget in the Android README,
  including why the BLE connection interval (~5–11ms) is a hard floor and why
  raising the accelerometer ODR is *not* a safe latency tweak (three tuned
  constants are expressed in samples, not time, and would silently change
  meaning).

- App launcher icon, replacing the stock Android placeholder: the gold
  casting tipped 45° (mouth up-left, handle down-right, matching the build
  photo) over a radial champagne-to-slate-grey gradient, with a small
  Bluetooth badge upper right. Pure vector adaptive icon — two
  `VectorDrawable`s, no raster assets at any density, and no legacy PNG
  fallback needed since `minSdk` is 31. The bell is authored upright and
  tipped by a single group rotation, so the geometry stays editable; every
  point is inside the radius-36 adaptive-icon safe zone (values checked and
  recorded in the file header).

## v0.1 — 2026-08-29

Initial prototype.

- 3D-printed handbell body ([3dprint/handbell.scad](3dprint/handbell.scad)), plus test prints for the battery cradle, cone collar, feather plate, LIS3DH plate, and rod collar mounts.
- Firmware for the Feather ESP32 V2 reading an LIS3DH over I2C and detecting ring gestures ([firmware/feather_transmitter](firmware/feather_transmitter)).
- Ring events transmitted wirelessly two ways:
  - ESP-NOW to an ESP32-DEVKITC-V4 receiver, forwarded over USB serial ([firmware/devkit_receiver](firmware/devkit_receiver)).
  - BLE directly to a PC.
- PC-side test listeners for both paths, playing a tone on ring detection ([firmware/receiver_tests](firmware/receiver_tests)).

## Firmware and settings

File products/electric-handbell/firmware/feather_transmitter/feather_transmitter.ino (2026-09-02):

/*
  ============================================================================
  Wireless Handbell — Feather ESP32 V2 Transmitter (BLE-only, low-latency)
  ============================================================================
  Reads an Adafruit LIS3DH accelerometer, detects a "ring" the way a real
  handbell rings (a forward swing followed by a sudden stop), and transmits
  the event over BLE (GATT notify) to a phone running the Handbell Receiver
  Android app.

  RING DETECTION — modeling a real handbell
    A real handbell doesn't ring from motion alone. The clapper swings only
    fore/aft, sprung so it won't strike on the backswing and needs real force
    to strike at all. What actually rings it: you swing the bell forward, you
    STOP the bell, and the clapper keeps going and hits the casting.

    So this is not "acceleration exceeded a threshold" (v0.2 and earlier —
    which is why picking the bell up or tapping the handle would false-trigger).
    Instead:
      1. Gravity is separated out with a slow low-pass filter, leaving only
         linear acceleration. (The old code compared a magnitude that had 1g
         of gravity baked into it, so orientation alone moved the number.)
      2. Forward-axis linear acceleration is integrated into a forward
         VELOCITY, using a leaky integrator so sensor bias can't drift it.
      3. The detector arms once the bell is genuinely moving (ARM_SPEED), not
         just jostled.
      4. While armed, a sharp deceleration (RING_STOP_DECEL_THRESHOLD, or the
         gentler DAMP_STOP_DECEL_THRESHOLD if this isn't shaping up to be a
         ring) counts as the bell being stopped. That's when a clapper strikes —
         and the moment the gesture gets classified: peak forward velocity at
         or above RING_FORWARD_VELOCITY means it was a ring, anything less
         means it was a damp. See DECIDE AT THE STOP below.

    Why this rejects the false triggers:
      - Tapping the handle: large acceleration spike, but it nets ~zero
        velocity, so the detector never arms.
      - Picking the bell up: slow, and mostly along gravity rather than the
        forward axis; doesn't reach arm velocity.
      - Backswing: arming requires POSITIVE forward velocity, so returning
        the bell can't ring it — the same asymmetry the clapper springs give
        a real bell, for free.
      - Multiple rings per swing: after a ring the detector must see velocity
        fall back below RELEASE_VELOCITY before it can re-arm, on top of
        REFRACTORY_MS.

    IMPORTANT — set FORWARD_AXIS/FORWARD_SIGN below to match how your LIS3DH
    is actually mounted, or none of this works. Set CALIBRATION_MODE 1 and
    follow the procedure there; it takes about 30 seconds.

  SUSTAIN AND DAMP — v0.4
    A real handbell keeps ringing after the strike until it naturally damps
    out, or until the ringer brings it to their body to stop it (touching the
    casting kills the vibration). The Android app plays a multi-second
    decaying tone per ring rather than a short fixed blip, so this firmware
    needs to tell it when to cut that tone off early. That's a "damp", the
    standard handbell term.

    RING AND DAMP ARE NOT SYMMETRIC — this is the key asymmetry to preserve:

      A ring is DIRECTIONAL. The clapper only travels fore/aft and is sprung
      against striking backward, so only a forward swing + stop rings the
      bell. That stays a single-axis test on forwardVelocity.

      A damp is OMNIDIRECTIONAL. Physically it's just "the casting contacted
      something" — any orientation works. And in practice the ringer's arm
      geometry means the bell rarely comes back along the ring axis at all:
      bringing it to the chest/shoulder typically contacts around 45° off the
      normal plane of motion, laterally. An earlier version tested only for
      backward motion along the forward axis, which forced the ringer to
      rotate the bell in-hand to damp it — exactly backwards from how the
      gesture actually wants to work.

    So damp detection works on the full 3D velocity vector, firing on a sharp
    deceleration ALONG THE DIRECTION OF TRAVEL (dot product of linear
    acceleration with the unit motion vector) rather than along any fixed
    axis. That's what makes it work at 45° lateral, straight down, or
    anywhere else.

    Damp is a separate BLE characteristic (BLE_CHAR_DAMP_UUID) rather than a
    field on RingEvent, since it's a genuinely different signal — "stop
    whatever is currently sounding," not "a new strike happened."

  DECIDE AT THE STOP, NOT AT ARMING — and why the obvious approach fails
    There is ONE armed state, not one per gesture. A motion arms on speed
    alone, and which gesture it was is decided when it stops, from the peaks
    accumulated over the whole gesture.

    The first attempt armed each gesture separately — ring when forward
    velocity passed its threshold, damp when speed passed its own while
    outside a forward cone. That cannot work, and the reason is worth
    recording so it doesn't get reintroduced:

      speed >= |forwardVelocity| ALWAYS, by definition of a vector magnitude.

    So on a forward swing, speed crosses the damp threshold strictly BEFORE
    forward velocity crosses the ring threshold. Every sample in that window
    is another chance for the damp arm to fire first, and a real swing is an
    arc with lateral and gravity-leakage components, so its direction wanders
    in and out of any forward cone you pick. The result: the damp state stole
    a large fraction of ring gestures, which then landed as silent damps
    instead of rings. Widening or narrowing the cone only trades ring misses
    against damp misses — the race is structural, not a tuning problem.

    Deciding at the stop removes the race entirely: by then the full gesture
    has happened, and peak forward velocity cleanly separates the two (a damp
    travels back toward the body, so its peak forward velocity is near zero or
    negative, nowhere near a ring's).

    The one thing this design must guard against is the strike recoil right
    after a ring reading as a damp and killing the tone it just started —
    hence POST_RING_DAMP_LOCKOUT_MS.

    Note "decided at the stop" does NOT mean the two gestures must share a
    stop threshold. The classification input — peak forward velocity — is a
    running peak available at every sample, so which gesture a motion would
    be, and therefore which threshold applies to it, is known continuously.
    They get separate thresholds precisely because they're physically
    different events: arresting a committed swing versus resting the casting
    against your shoulder.

  DON'T REQUIRE THE BELL TO STOP BETWEEN GESTURES
    A related early mistake: the post-event settle required speed to fall
    below RELEASE_VELOCITY before anything could re-arm. But ringing and then
    damping is ONE continuous motion — the bell never comes to rest in
    between — so the detector sat in settling right through the damp. Settling
    now waits only for the refractory window and for the deceleration spike
    itself to pass, never for the bell to be still.

  v0.2 NOTE — this variant drops ESP-NOW/WiFi entirely. It was built for a
  live demo where the receiver is an Android phone (Android has no ESP-NOW
  support), and removing the WiFi stack has the added benefit of eliminating
  WiFi/BLE radio coexistence arbitration, which was a source of timing
  jitter in v0.1. If you need the dual-transport (ESP-NOW + BLE) version
  again — e.g. to talk to devkit_receiver.ino/pc_serial_listener.py — it's
  preserved at the "v0.1" git tag.

  HARDWARE
    - Adafruit ESP32 Feather V2
    - Adafruit LIS3DH breakout, wired over I2C (STEMMA QT or SDA/SCL + 3V + GND)
    - 500mAh LiPo on the JST connector

  BATTERY TELEMETRY — how it works and its limits
    The Feather V2 has no fuel-gauge IC (unlike the ESP32-S2/S3 Feathers) —
    just a resistor divider from BAT to the analog pin A13, and a charge LED
    wired directly to the MCP73831 charger with no GPIO tap. So percentage,
    "charging", and "USB-powered with no battery" are all *inferred* from one
    noisy voltage reading over time, not measured directly:
      - Percentage comes from a standard LiPo voltage curve lookup (approximate).
      - A near-0V reading means no battery is physically present — since the
        board is alive to report anything at all, it must be running on USB.
      - Charging vs. discharging is judged by the *trend* over a rolling
        window (rising = charging, falling = discharging). A flat reading
        near max voltage is reported as "resting" rather than guessed at,
        since a fully-charged battery on USB and a fully-charged battery
        just sitting unplugged look identical from voltage alone.
    See BATT_* constants below to tune thresholds against your actual pack.

  LATENCY MEASUREMENT
    RingEvent.timestampMs is millis() on THIS board — meaningless compared
    directly against the phone's clock. The Android app reads
    BLE_CHAR_TIME_UUID once after connecting to estimate the offset between
    the two clocks (see TimeCharacteristicCallbacks below), then uses that
    to compute true ring-to-tone latency on its end.

  LIBRARIES (Arduino Library Manager)
    - Adafruit LIS3DH
    - Adafruit Unified Sensor
    - NimBLE-Arduino (by h2zero)   <-- NOT the stock ESP32 BLE library

  SETUP STEPS
    1. Flash this sketch to the Feather.
    2. It advertises as "WirelessHandbell" over BLE — no pairing needed.
    3. Run the Handbell Receiver Android app (see /android) to connect and
       play a tone on each ring.

  LATENCY TUNING — what changed from v0.1 and why
    - No WiFi/ESP-NOW: one fewer radio stack competing for airtime with BLE.
    - LIS3DH runs at 400Hz in HIGH RESOLUTION (12-bit) mode. v0.2 used
      1.6kHz low-power (8-bit) on the theory that raw sample rate was all
      that mattered, but the ring detector now integrates acceleration into
      velocity, and 8-bit data is too coarse to integrate without the bias
      error swamping the result. 400Hz still gives 2.5ms granularity, which
      is far below the ~10ms of BLE latency downstream, so this costs
      nothing perceptible and buys much cleaner detection.
    - Sampling is paced to the sensor's output rate rather than polled flat
      out — reading faster than the ODR just re-reads the same sample and
      wastes I2C bandwidth that BLE could be using.
    - The BLE connection interval is renegotiated down to 7.5–15ms with
      zero slave latency as soon as a phone connects, via
      NimBLEServer::updateConnParams(). Default negotiated intervals can
      land closer to 30–50ms, which adds directly to notify latency.
    - TX power raised to +9dBm to reduce the odds of a retry/retransmit
      (which would show up as a latency spike) at the cost of some battery
      life — acceptable for a short demo.
  ============================================================================
*/

#include <Wire.h>
#include <Adafruit_LIS3DH.h>
#include <Adafruit_Sensor.h>
#include <NimBLEDevice.h>

// ---------------------------------------------------------------------------
// CONFIG — tune these for your bell / mounting
// ---------------------------------------------------------------------------
// --- Mounting orientation --------------------------------------------------
// Which LIS3DH axis points in the direction the bell travels when swung
// forward, and which sign of that axis is "forward". THIS MUST MATCH YOUR
// PHYSICAL MOUNTING — see CALIBRATION_MODE below to determine it empirically.
// Set from the build photo: the LIS3DH is mounted flat on the rod's wide face,
// long axis along the rod, component side facing outward toward the ringer.
// The PCB normal (Z) therefore points out of the rod face at the ringer, and a
// handbell's fore/aft swing runs along that normal — so forward (away from the
// ringer) is -Z. VERIFY WITH CALIBRATION_MODE ANYWAY: the axis is confidently
// Z, but the sign depends on which way the board faces and is easy to get
// backwards. A flipped sign means the detector arms on the backswing instead.
#define AXIS_X 0
#define AXIS_Y 1
#define AXIS_Z 2
#define FORWARD_AXIS   AXIS_Z
#define FORWARD_SIGN   (-1.0f)
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
void loop() {
  unsigned long nowMs = millis();
  unsigned long nowUs = micros();

  // Pace sampling to the sensor's ODR; polling faster just re-reads the same
  // sample. Battery telemetry still gets a chance to run on skipped iterations.
  if ((unsigned long)(nowUs - lastSampleUs) < SAMPLE_INTERVAL_US) {
    sampleBatteryIfDue(nowMs);
    return;
  }
  float dt = (nowUs - lastSampleUs) / 1000000.0f;
  lastSampleUs = nowUs;
  // Guard the first iteration (and any stall) from producing a huge dt that
  // would slam the integrator.
  if (dt > 0.05f) dt = 0.05f;

  sensors_event_t event;
  lis.getEvent(&event);
  float ax = event.acceleration.x;   // m/s^2, gravity included
  float ay = event.acceleration.y;
  float az = event.acceleration.z;

  // --- Separate gravity from linear acceleration ---------------------------
  if (!gravityInitialized) {
    gravityX = ax; gravityY = ay; gravityZ = az;
    gravityInitialized = true;
  } else {
    gravityX = GRAVITY_LPF_ALPHA * gravityX + (1.0f - GRAVITY_LPF_ALPHA) * ax;
    gravityY = GRAVITY_LPF_ALPHA * gravityY + (1.0f - GRAVITY_LPF_ALPHA) * ay;
    gravityZ = GRAVITY_LPF_ALPHA * gravityZ + (1.0f - GRAVITY_LPF_ALPHA) * az;
  }
  float linX = ax - gravityX;
  float linY = ay - gravityY;
  float linZ = az - gravityZ;
  float linMag = sqrtf(linX * linX + linY * linY + linZ * linZ);

  // (No forward-axis acceleration term any more: the stop is now detected
  // along the direction of travel — decelAlongTravel below — which reduces to
  // the same thing for a forward swing but also works for an off-axis damp.)

  // --- Integrate to a 3D velocity vector (leaky, so bias can't accumulate) --
  velX = velX * VELOCITY_DECAY + linX * dt;
  velY = velY * VELOCITY_DECAY + linY * dt;
  velZ = velZ * VELOCITY_DECAY + linZ * dt;

  // When the bell is genuinely still, zero the integrator outright — and the
  // gesture peaks with it, so a stale peak from an earlier motion can't leak
  // into how the next gesture gets classified.
  if (linMag < REST_ACCEL_THRESHOLD) {
    if (restSamples < REST_SAMPLES_REQUIRED) {
      restSamples++;
    } else {
      velX = velY = velZ = 0.0f;
      resetGesturePeaks();
    }
  } else {
    restSamples = 0;
  }

  // Forward component is the ring/damp discriminator; the full magnitude is
  // what arms a gesture and what the damp's stop is measured against.
  float forwardVelocity = FORWARD_SIGN * (FORWARD_AXIS == AXIS_X ? velX
                                        : FORWARD_AXIS == AXIS_Y ? velY
                                                                 : velZ);
  float speed = sqrtf(velX * velX + velY * velY + velZ * velZ);

  // Capture the direction of travel at the fastest point of the gesture, and
  // measure deceleration along it. This is what makes damp orientation-blind.
  if (speed > peakSpeed) {
    peakSpeed = speed;
    if (speed > 1e-6f) {
      travelDirX = velX / speed;
      travelDirY = velY / speed;
      travelDirZ = velZ / speed;
    }
  }
  float decelAlongTravel = -(linX * travelDirX + linY * travelDirY + linZ * travelDirZ);

  // Jerk: how fast that deceleration is CHANGING. Contact spikes it; a
  // voluntary arm slowdown doesn't. Differenced across a short window rather
  // than sample-to-sample, so ADC noise doesn't swamp it.
  float oldestDecel = decelHistory[decelHistoryIdx];
  decelHistory[decelHistoryIdx] = decelAlongTravel;
  decelHistoryIdx = (decelHistoryIdx + 1) % JERK_WINDOW_SAMPLES;
  if (jerkSamples < JERK_WINDOW_SAMPLES) jerkSamples++;
  // Until the window has refilled since the last reset, report 0 rather than
  // a difference against stale data.
  float decelJerk = (jerkSamples >= JERK_WINDOW_SAMPLES)
                        ? (decelAlongTravel - oldestDecel) / (JERK_WINDOW_SAMPLES * dt)
                        : 0.0f;

  if (linMag > peakLinearAccel) peakLinearAccel = linMag;
  if (forwardVelocity > peakForwardVelocity) peakForwardVelocity = forwardVelocity;

#if CALIBRATION_MODE == 1
  static unsigned long lastCalPrintMs = 0;
  if (nowMs - lastCalPrintMs >= 50) {
    lastCalPrintMs = nowMs;
    Serial.printf("g=[%6.2f %6.2f %6.2f]  lin=[%6.2f %6.2f %6.2f]  vFwd=%6.2f\n",
                  gravityX, gravityY, gravityZ, linX, linY, linZ, forwardVelocity);
  }
#else
#if CALIBRATION_MODE == 2
  // Trace only while the bell is actually moving, so the log isn't buried in
  // idle noise. 50Hz is enough to see the shape of a swing without flooding
  // the serial link (which would itself add latency).
  {
    static unsigned long lastTracePrintMs = 0;
    if (linMag >= REST_ACCEL_THRESHOLD && nowMs - lastTracePrintMs >= 20) {
      lastTracePrintMs = nowMs;
      // peakFwd is the discriminator: at the stop, >= RING_FORWARD_VELOCITY
      // is a ring, anything less is a damp. Watch it across both gestures to
      // confirm they separate cleanly.
      Serial.printf("vFwd=%6.2f  speed=%5.2f  decel=%6.1f  jerk=%7.0f  peakFwd=%5.2f  peakSpd=%5.2f  state=%s\n",
                    forwardVelocity, speed, decelAlongTravel, decelJerk,
                    peakForwardVelocity, peakSpeed,
                    ringState == RING_IDLE    ? "idle"
                    : ringState == RING_ARMED ? "ARMED"
                                              : "settling");
    }
  }
#endif
  // --- Gesture state machine -----------------------------------------------
  // Arm on motion; classify at the stop. See "DECIDE AT THE STOP" in the
  // header for why this must not be split into per-gesture armed states.
  switch (ringState) {
    case RING_IDLE:
      // Direction-agnostic: any real motion arms. A tap on the handle spikes
      // acceleration but nets ~zero velocity, so it never gets here.
      if (speed >= ARM_SPEED) {
        ringState = RING_ARMED;
      }
      break;

    case RING_ARMED: {
      // What this gesture would be if it stopped right now. Depends only on a
      // running peak, so it's known at every sample — which is what lets the
      // two gestures use different stop thresholds.
      bool wouldRing = (peakForwardVelocity >= RING_FORWARD_VELOCITY);
      float stopThreshold = wouldRing ? RING_STOP_DECEL_THRESHOLD
                                      : DAMP_STOP_DECEL_THRESHOLD;
      bool stopped = (decelAlongTravel >= stopThreshold);

      // A damp must additionally look like a CONTACT rather than the smooth
      // slowdown of the arm approaching — see CONTACT vs APPROACH in the
      // config. Ring keeps a magnitude-only test.
      if (stopped && !wouldRing && decelJerk < DAMP_CONTACT_JERK) {
        stopped = false;
        // Rate-limited so a long approach doesn't flood the log. This line
        // firing on gestures you meant as damps means DAMP_CONTACT_JERK is
        // set too high.
        static unsigned long lastSoftLogMs = 0;
        if (nowMs - lastSoftLogMs >= 300) {
          lastSoftLogMs = nowMs;
          Serial.printf("(damp: decel %.1f ok, jerk %.0f too soft)\n",
                        decelAlongTravel, decelJerk);
        }
      }

      if (stopped) {
        if (wouldRing) {
          // Travelled forward with real commitment: this is a strike.
          emitRing(nowMs);
          lastRingMs = nowMs;
        } else if (nowMs - lastRingMs >= POST_RING_DAMP_LOCKOUT_MS) {
          // Moved and stopped, but not a forward swing: a damp.
          emitDamp(nowMs, decelAlongTravel, decelJerk);
        } else {
          // Within the post-ring lockout. This is almost certainly the
          // strike's own recoil, not a real damp — swallow it rather than
          // killing the tone that was just started.
          Serial.println("(recoil suppressed)");
        }
        ringState = RING_SETTLING;
        settleUntilMs = nowMs + REFRACTORY_MS;
      } else if (speed < RELEASE_VELOCITY) {
        // Motion petered out without a definite stop — nothing to report.
        ringState = RING_IDLE;
        resetGesturePeaks();
      }
      break;
    }

    case RING_SETTLING:
      // Wait out the refractory window and for the deceleration spike itself
      // to pass. Deliberately does NOT wait for the bell to come to rest:
      // ringing and then damping is one continuous motion, and requiring a
      // full stop in between left the detector sitting here right through the
      // damp. See "DON'T REQUIRE THE BELL TO STOP BETWEEN GESTURES".
      // Uses the lower of the two thresholds, so the spike has decayed past
      // the point where either gesture could immediately re-fire on it.
      if (nowMs >= settleUntilMs && decelAlongTravel < DAMP_STOP_DECEL_THRESHOLD) {
        ringState = RING_IDLE;
        resetGesturePeaks();
      }
      break;
  }
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

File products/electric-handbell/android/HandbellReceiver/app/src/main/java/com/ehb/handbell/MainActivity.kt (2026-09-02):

package com.ehb.handbell

import android.Manifest
import android.annotation.SuppressLint
import android.bluetooth.BluetoothAdapter
import android.bluetooth.BluetoothManager
import android.content.Intent
import android.os.Bundle
import android.os.SystemClock
import android.widget.AdapterView
import android.widget.ArrayAdapter
import android.widget.Button
import android.widget.ListView
import android.widget.Spinner
import android.widget.TextView
import androidx.activity.result.contract.ActivityResultContracts
import androidx.appcompat.app.AppCompatActivity
import java.util.Locale

class MainActivity : AppCompatActivity() {

    private lateinit var tvStatus: TextView
    private lateinit var tvRingCount: TextView
    private lateinit var tvLastPeak: TextView
    private lateinit var tvLatency: TextView
    private lateinit var tvBattery: TextView
    private lateinit var tvClearLog: TextView
    private lateinit var btnDamp: Button
    private lateinit var spinnerPitch: Spinner
    private lateinit var btnPitchDown: Button
    private lateinit var btnPitchUp: Button
    private lateinit var spinnerInstrument: Spinner
    private lateinit var lvRingLog: ListView
    private lateinit var busyOverlay: android.view.View
    private lateinit var rootView: android.view.View

    private lateinit var ringPlayer: RingPlayer
    private lateinit var ringLogAdapter: ArrayAdapter<String>
    private var bleClient: BleRingClient? = null
    private var ringCount = 0

    /** Raw per-ring data, newest first -- kept separately from the adapter's
     *  display strings so toggling detail level can re-render history. */
    private data class RingRecord(
        val ringId: Long,
        val peakG: Float,
        val dynamicLevel: DynamicLevel,
        val totalMs: Long?,
        val bleMs: Long?,
        val appMs: Long?,
    )

    private val ringHistory = ArrayDeque<RingRecord>()
    private var lastRing: RingRecord? = null

    // Tap tvLatency to flip this -- deliberately no visible toggle control.
    private var showLatencyDetails = false

    // Set true right before a +/- nudge programmatically moves the spinner's
    // selection, and cleared by the listener itself (not by the code that set it)
    // when it actually fires -- Spinner.setSelection()'s onItemSelected callback
    // is documented inconsistently across Android versions as either synchronous
    // or posted, so this has to survive either timing rather than being reset
    // immediately after the setSelection() call returns.
    private var suppressNextSpinnerCallback = false

    private companion object {
        const val MAX_LOG_ENTRIES = 200
        const val PREFS_NAME = "handbell_prefs"
        const val KEY_PITCH_NAME = "pitch_name"
        const val KEY_INSTRUMENT_NAME = "instrument_name"
    }

    private val requestPermissions =
        registerForActivityResult(ActivityResultContracts.RequestMultiplePermissions()) { results ->
            if (results.values.all { it }) {
                ensureBluetoothEnabledThenStart()
            } else {
                tvStatus.text = "Bluetooth permissions are required to receive rings."
            }
        }

    private val requestEnableBluetooth =
        registerForActivityResult(ActivityResultContracts.StartActivityForResult()) {
            startBleClient() // proceed regardless; start() itself reports "Bluetooth is off" if declined
        }

    override fun onCreate(savedInstanceState: Bundle?) {
        super.onCreate(savedInstanceState)
        setContentView(R.layout.activity_main)

        rootView = findViewById(R.id.root)
        tvStatus = findViewById(R.id.tvStatus)
        tvRingCount = findViewById(R.id.tvRingCount)
        tvLastPeak = findViewById(R.id.tvLastPeak)
        tvLatency = findViewById(R.id.tvLatency)
        tvBattery = findViewById(R.id.tvBattery)
        tvClearLog = findViewById(R.id.tvClearLog)
        btnDamp = findViewById(R.id.btnDamp)
        spinnerPitch = findViewById(R.id.spinnerPitch)
        btnPitchDown = findViewById(R.id.btnPitchDown)
        btnPitchUp = findViewById(R.id.btnPitchUp)
        spinnerInstrument = findViewById(R.id.spinnerInstrument)
        lvRingLog = findViewById(R.id.lvRingLog)
        busyOverlay = findViewById(R.id.busyOverlay)

        ringLogAdapter = ArrayAdapter(this, R.layout.item_ring_log, R.id.tvRingLogItem, mutableListOf<String>())
        lvRingLog.adapter = ringLogAdapter

        tvLatency.setOnClickListener {
            showLatencyDetails = !showLatencyDetails
            lastRing?.let { tvLatency.text = "Latency: ${formatLatency(it, showLatencyDetails)}" }
            refreshLogDisplay()
        }

        tvClearLog.setOnClickListener {
            ringHistory.clear()
            ringLogAdapter.clear()
        }

        // Works whether or not the bell is connected -- it acts on the local
        // audio stream, not on the bell.
        btnDamp.setOnClickListener { ringPlayer.damp() }

        val prefs = getSharedPreferences(PREFS_NAME, MODE_PRIVATE)
        val savedPitch = HandbellPitches.byName(prefs.getString(KEY_PITCH_NAME, null) ?: "")
            ?: HandbellPitches.DEFAULT
        val savedInstrument = prefs.getString(KEY_INSTRUMENT_NAME, null)?.let { name ->
            runCatching { Instrument.valueOf(name) }.getOrNull()
        } ?: Instrument.BELL

        ringPlayer = RingPlayer(this)
        ringPlayer.setOnBusyChangedListener { busy ->
            runOnUiThread { busyOverlay.visibility = if (busy) android.view.View.VISIBLE else android.view.View.GONE }
        }
        ringPlayer.prepare(savedPitch, savedInstrument)
        setUpPitchSpinner(savedPitch)
        setUpInstrumentSpinner(savedInstrument)

        btnPitchDown.setOnClickListener { nudgePitch(-1) }
        btnPitchUp.setOnClickListener { nudgePitch(+1) }

        requestPermissions.launch(
            arrayOf(Manifest.permission.BLUETOOTH_SCAN, Manifest.permission.BLUETOOTH_CONNECT)
        )
    }

    private fun setUpPitchSpinner(initialPitch: HandbellPitch) {
        val pitchNames = HandbellPitches.ALL.map { it.name }
        val adapter = ArrayAdapter(this, R.layout.item_pitch_spinner, R.id.tvPitchItem, pitchNames)
        adapter.setDropDownViewResource(R.layout.item_pitch_spinner)
        spinnerPitch.adapter = adapter
        spinnerPitch.setSelection(HandbellPitches.ALL.indexOf(initialPitch))
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

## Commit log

2026-08-29 Initial commit: 3D print model and firmware prototype
    [TestPieces.3mf, handbell.scad, test_battery_cradle.stl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]
2026-08-29 v0.2 WIP: BLE-only low-latency firmware + Android demo receiver
    - feather_transmitter.ino: drop ESP-NOW/WiFi, raise LIS3DH ODR to 1.6kHz,
    remove sample-loop throttle, request 7.5-15ms BLE connection interval
    with zero slave latency on connect, raise TX power to +9dBm.
    - New android/HandbellReceiver app: BLE scan/connect/subscribe, requests
    CONNECTION_PRIORITY_HIGH, plays a pre-synthesized velocity-sensitive
    bell tone via SoundPool with no synthesis on the ring-event hot path.
    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
2026-08-29 Add battery telemetry: percentage, time remaining, charge state
    - feather_transmitter.ino: low-priority battery sampling (every 5s, never
    gating the ring-detection loop). Infers percent from a LiPo voltage
    curve on A13, detects 'no battery / USB-powered' from a near-0V reading,
    and judges charging vs discharging from a 60s voltage trend, since the
    Feather V2 has no fuel-gauge chip and no CHG-status GPIO. Sent over a
    new second BLE characteristic (...0003).
    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
2026-09-01 Add end-to-end ring-to-tone latency measurement
    - feather_transmitter.ino: new read-only BLE_CHAR_TIME_UUID characteristic
    that returns millis() fresh on every read, for clock-sync purposes.
    - BleRingClient: generalized the descriptor-write queue into a general
    GATT operation queue (reads + writes), since Android allows only one
    outstanding GATT operation at a time. Reads the time characteristic once
    per connection, bracketing the round trip (midpoint method) to estimate
    the offset between the Feather's millis() and the phone's
    SystemClock.elapsedRealtime().
    - MainActivity: shows total ring-to-tone latency per ring, broken down into
    ring->phone (BLE) and phone->sound (app) legs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
    [MainActivity.kt, feather_transmitter.ino]
2026-09-01 UI pass: unobtrusive battery/latency, add ring log with clear
    - Battery moved to a small, dim top-left corner -- background info now,
    not a focal point.
    - Latency defaults to just the total; tap the latency line to toggle the
    ring->phone / phone->sound breakdown (no visible toggle control, by
    design). Ring log entries respect the same toggle.
    - New scrolling ring log (ListView, newest first) showing the same info
    as 'last ring' for every ring this session, plus a small 'Clear'
    control that resets the log without touching the running ring counter.
    - Picked up Android Studio's AGP 8.13.2 / Gradle 8.13 wrapper bump.
    [MainActivity.kt]
2026-09-01 3D print iteration: rod/cone collar updates, handbell.scad tweaks
    - Update handbell.scad (mounting/collar geometry adjustments)
    - Add cone and rod exports (.3mf/.stl) plus their /out renders
    - Add rod collar test print v3/v4
    [cone.3mf, cone.stl, handbell.scad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]
2026-09-01 Rewrite ring detection to model real handbell physics
    Detection was a bare acceleration-magnitude threshold, which fired on any
    motion -- picking the bell up or tapping the handle would ring it, and one
    motion could produce several rings.
    Now models what actually rings a handbell: a forward swing followed by a
    sudden stop (the moment the clapper catches up and strikes the casting).
    - Separate gravity from linear acceleration with a slow low-pass filter.
    The old code compared a magnitude with 1g of gravity baked in, so
    orientation alone moved the number.
    - Integrate forward-axis linear acceleration into a forward velocity using
    a leaky integrator, so sensor bias can't drift it.
    - Arm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
    [feather_transmitter.ino]
2026-09-01 Set forward axis from build photo; add swing-trace diagnostic
    The mounting photo shows the LIS3DH flat on the rod's wide face, long axis
    along the rod, component side outward. The PCB normal (Z) therefore points
    at the ringer, and the fore/aft swing runs along that normal -- so forward
    is -Z, not the AXIS_Y placeholder that was in there.
    The photo also shows the sensor mounted well above the wrist pivot, so the
    motion is largely rotational and the bell tips through a large angle. That
    makes gravity-rotation leakage into the forward axis a bigger tuning
    concern than first estimated, since a slow forward tilt can accumulate
    phantom forward velocity. Documented with a direction to tune.
    - CAL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
    [feather_transmitter.ino]
2026-09-01 3D print iteration: cone/collar updates
    [cone.3mf, cone.stl, test_cone_collar.3mf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]
2026-09-01 Expand to six musical dynamic levels; fix volume, widen range
    Replaced the three ad-hoc tone 'buckets' with the six standard musical
    dynamic levels (pp, p, mp, mf, f, ff), evenly spread across the bell's
    observed realistic peak range (1.6g-5.0g per ring-log data). New
    DynamicLevel.kt is the single source of truth, used by both RingPlayer
    (tone shape + volume) and the UI (detected-dynamic display), so they
    can't drift out of sync.
    Also fixes a real bug: playback volume never actually varied between
    levels. synthesizeBellTone() scaled the waveform by 'strength' but then
    renormalized every buffer to the same fixed peak amplitude, canceling the
    scaling back out -- SoundPool.play() was also alwa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
    [MainActivity.kt]
2026-09-01 Add sustain and mute: natural decay + backward-stop to cut it short
    Real handbells keep ringing after a strike until they naturally damp out
    or the ringer presses the bell to their body. Implements both halves:
    Firmware:
    - MUTE gesture detection: a backward swing (negative forward velocity)
    followed by a sudden stop -- the mirror image of ring detection, and
    physically exclusive with it (a swing can't be armed forward and
    backward at once). Unified into one state machine: RING_IDLE ->
    RING_ARMED_FORWARD/RING_ARMED_BACKWARD -> RING_SETTLING -> RING_IDLE.
    - New BLE_CHAR_MUTE_UUID characteristic, minimal MuteEvent payload
    (just a timestamp -- it's a pure 'stop sounding' signal, not a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
    [MainActivity.kt, feather_transmitter.ino]
2026-09-02 Omnidirectional damp, manual damp button, raise volume floor
    Three fixes from live testing:
    1. Damp detection was too narrow. It was implemented as the mirror image
    of ring detection -- backward motion along the forward axis -- but a
    damp is physically just 'the casting contacted something', and arm
    geometry means the bell actually comes back to the body around 45 deg
    off the ring plane, laterally. That forced the ringer to rotate the
    bell in-hand to damp it, exactly backwards from how the gesture wants
    to work.
    Damp now works on the full 3D velocity vector: velocity is integrated
    on all three axes, damp arms on SPEED in any direction outside a
    forward exclusion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
    [MainActivity.kt, feather_transmitter.ino]
2026-09-02 Fix ring/damp detection dropping most gestures
    Regression from the omnidirectional damp change. Two structural bugs, both
    mine:
    1. ARMING RACE. Ring and damp each had their own armed state, entered on
    their own threshold. But speed >= |forwardVelocity| by definition of a
    vector magnitude, so on a forward swing the damp speed threshold (0.60)
    was ALWAYS crossed before the ring forward threshold (0.70). Every
    sample in that window re-tested the forward cone, and a real swing is an
    arc whose direction wanders in and out of any cone you pick -- so the
    damp state stole a large share of ring gestures, which then landed as
    silent damps. Widening or narrowing the cone only trad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
    [feather_transmitter.ino]
2026-09-02 Lower damp force threshold; give each gesture its own
    A damp can be much gentler than a ring -- resting the casting against a
    shoulder rather than arresting a committed swing -- and soft damps weren't
    registering.
    Two changes:
    - Split STOP_DECEL_THRESHOLD back into RING_ (12.0) and DAMP_ (6.0). The
    previous commit merged them on the reasoning that the stop must be
    detected before the gesture can be classified, so the threshold couldn't
    depend on the outcome. That was wrong: the classification input
    (peakForwardVelocity) is a running peak available at every sample, so
    which gesture a motion would be -- and therefore which threshold applies
    -- is known continuously, not only after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
    [feather_transmitter.ino]
2026-09-02 Damp on contact, not deceleration magnitude: add jerk gate
    DAMP_STOP_DECEL_THRESHOLD alone cannot separate a gentle damp from the arm
    slowing down as it approaches the shoulder -- both produce decelerations of
    similar magnitude. At 6.0 soft damps were missed; at 5.0 it fired
    mid-approach, before the casting touched anything. Both edges of the same
    squeeze; there is no value in between that works.
    Magnitude is the wrong discriminator. Contact is distinguished by
    SUDDENNESS: a collision changes acceleration within a few milliseconds,
    while a voluntary arm slowdown ramps over a tenth of a second or more --
    roughly an order of magnitude apart in jerk.
    A damp now requires both enough decelerati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
    [feather_transmitter.ino]
2026-09-02 Add pitch selection: standard handbell pitches, C3-C8
    New HandbellPitch.kt covers the standard chromatic range of a 5-octave
    handbell choir set (C3-C8, 61 pitches), spelled with flats (Bb4, not A#4)
    per handbell convention, at 12-tone equal temperament (A4=440Hz). The
    existing tone was already tuned to A5 (880Hz), so that's the default.
    A Spinner near the top of the app (dark-safe popupBackground + custom row
    layout, since AppCompat's default spinner popup theming can't be trusted
    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
2026-09-02 Add instant pitch nudge buttons; fix high-pitch harmonic aliasing
    Two independent fixes:
    1. INSTANT +/- NUDGE. The dropdown's ~1s re-synthesis was too slow for a
    single-button semitone nudge. RingPlayer.nudgeSemitone() avoids
    re-synthesis entirely: a semitone is a SoundPool playback-rate change of
    2^(1/12), trivially inside SoundPool's documented 0.5-2.0 range, so a
    nudge just replays the already-loaded tones at a shifted rate -- no
    waiting. Nudges accumulate onto that rate (tracked as the gap between
    basePitchIndex, what's actually baked into the loaded buffers, and
    currentPitchIndex, where the caller logically is) up to +/-9 semitones,
    past which a rebase resynthes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
    [MainActivity.kt]
2026-09-02 Add instrument selection: Bell, Piano, Guitar, Electric Guitar
    Procedural synthesis presets, not sampled recordings -- see the tradeoff
    writeup in the Android README's 'Instruments' section for why a soundfont
    + native synth engine (the more authentic option) was set aside as too
    large/risky an undertaking to build and verify without a real device to
    test against throughout, versus what's shipped here.
    New Instrument.kt enum (Bell, Piano, Guitar, Electric Guitar -- deliberately
    excludes organ/trumpet/clarinet, which are sustained/blown voices that
    don't fit the strike-and-decay model everything else in this app assumes).
    RingPlayer restructured around one raw-waveform generator per instrum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
    [MainActivity.kt]
2026-09-02 Block UI and suppress playback during instrument changes
    Hearing the old PITCH for one more ring during a pitch-dropdown transition
    is a harmless approximation. Hearing the wrong INSTRUMENT entirely is not
    -- it reads as a bug, not a brief delay. So instrument changes now get
    different treatment than pitch changes, which keep their existing
    fall-back-to-old-tone behavior unchanged.
    RingPlayer:
    - New blockPlaybackWhileBusy flag, set true by setInstrument() and cleared
    once the matching (current-generation) synthesis lands. play() checks it
    alongside the existing 'ready' check and drops the ring's audio (not the
    ring itself -- MainActivity still counts/logs it normally) while true.
    - Ne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
    [MainActivity.kt]
2026-09-02 Reduce ring-to-sound latency: play off the main thread, notify before logging
    Targeting the measured ~30ms. Three changes, all removing work that was
    sitting directly on the latency path -- no tuning constants touched, no
    detection behavior changed.
    APP (likely the largest win): play the tone on the BLE callback thread.
    onRing went through runOnUiThread and then did a String.format plus three
    view updates BEFORE calling play() -- despite a comment claiming it played
    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
2026-09-04 Restructure repo for multiple products
    Move the existing electric handbell (3dprint/, firmware/, android/,
    CHANGELOG.md, README.md) into products/electric-handbell/, and scaffold
    two new product folders:
    - products/song-bell/ — simpler 3D-printed bell that plays a song on
    its own
    - products/bell-pickup/ — electronic adapter/pickup for a real handbell
    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
    [TestPieces.3mf, cone.3mf, cone.stl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]
